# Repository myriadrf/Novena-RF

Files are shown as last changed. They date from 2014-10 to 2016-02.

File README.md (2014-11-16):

# Myriad-RF Module for the Novena Open Hardware Computing Plaform

This repository contains the design and manufacturing files for an RF module that adds 300MHz-3.8GHz broadband SDR transmit/receive capability to the [Novena Open Hardware Computing Platform](http://www.kosagi.com/w/index.php?title=Novena_Main_Page), along with RTL sources for interfacing implemented in the Novena FPGA.

## Contents

The directory structure for the hardware designs is as follows:

      /hardware/<version>/
          BOM/                   - bill of materials spreadsheet
          Gerbers/               - Gerber CAM files
          KiCAD/                 - KiCAD schematic and layout files
          Manufacturing/         - Additional manufacturing information
          PDF/                   - Schematic and layout PDFs
          Reports/               - DRC, ERC and drill reports

## Licensing

### Hardware design

The hardware design is licensed under a Creative Commons Attribution 3.0 Unported licence.

### FPGA design

The FPGA RTL is licensed under the Apache License, Version 2.0. However, please note that this does not extend to any files provided with the Xilinx design tools and see the relevant files for the associated terms and conditions.

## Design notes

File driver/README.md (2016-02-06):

# Myriad-RF Module SDR driver

This directory contains the complete SDR driver for the Myriad-RF Module.

## Contents

* fpga/ - FPGA project bridging LMS6002D to the EIM bus
* kernel/ - memory mapped access to sample/packet buffers
* host/ - host wrapper through a SoapySDR support module
* binary/ - pre-built FPGA image and kernel module

## Driver properties

### Configurable sample rates

* Max rate: 15.36 Msps
* Decimations: 1, 2, 4, 8, 16
* Interpolations: 1, 2, 4, 8, 16

### Selectable TX antenna switches

* "HB" - High band output (1500 - 3800 MHz)
* "BB" - Broadband output

The names for these switches can be used in the setAntenna() API call.

### Selectable RX antenna switches

* "LB" - Low band input (300 - 2200 MHz)
* "HB" - High band input (1500 - 3800MHz)
* "BB" - Broadband input

The names for these switches can be used in the setAntenna() API call.

### TX and RX Baseband filters

* 1.5 MHz to 28.0 MHz

### Adjustable transmit gain

* Overall: 0.0 to 56.0  dB
* "VGA1": -35.0 to -4.0 dB
* "VGA2": 0.0 to 25.0 dB

The names for these gain elements can be used in the setGain() API call.

### Adjustable receive gain

* Overall: 0.0  to 36.0  dB
* "VGA2": 0.0  to 30.0  dB
* "VGA1": 0.0  to 30.0  dB
* "LNA": 0.0  to 6.0  dB

The names for these gain elements can be used in the setGain() API call.

## Installing drivers

The following instructions allow one to build the driver for NovenaRF.
The instructions are intended for building locally on the device (for now).

### Dependencies

```
sudo apt-get install cmake g++ libusb-1.0-0-dev git
sudo apt-get remove libi2c-dev #fixes build issue
```

### Build the host driver

SoapySDR is a modular library and API for SDR devices.
First install the SoapySDR library:
https://github.com/pothosware/SoapySDR/wiki/BuildGuide

Then build and install the Novena RF support module:

```
git clone https://github.com/myriadrf/Novena-RF.git
cd Novena-RF/driver/host
mkdir build
cd build
cmake ../
make
sudo make install
sudo ldconfig
```

### Setup permissions and resources

There is a compiled FPGA image and kernel module in binary/
To install the files and to set the system permissions:

```
cd Novena-RF/driver/binary
sudo ./prepare_novena_rf.sh
```

Note: this script should be run after each reboot to set permissions and to load the module.

If, upon running the script, you get the error “could not insert module novena\_rf.ko: Invalid module format”, this means that the prebuilt `novena_rf.ko` doesn't match your kernel. Run `uname -a` to get the full version of your running kernel and `ls novena_rf.ko.*` to see if there's a matching version that you can copy over `novena_rf.ko`. If not, see the section below on building the kernel module.

## Hello Novena RF

Check that the installation detects NovenaRF support:

```
SoapySDRUtil --make="driver=novena"
```

## Platforms

### GNU Radio

Use the NovenaRF in GNU Radio through the gr-osmosdr API.
The user will have to install GNU Radio and SoapySDR first,
then install gr-osmosdr through the official project.
Make sure that soapy is one of the enabled components:

```
git clone git://git.osmocom.org/gr-osmosdr
cd gr-osmosdr/
```

## Pothos

Use the NovenaRF through Pothos SDR source and sink blocks
which support advanced timed streaming and burst controls.
Install SoapySDR first before following the build guide:
https://github.com/pothosware/pothos/wiki/BuildGuide

## osmo-trx

This is a branch of osmo-trx with novena support:
https://github.com/pothosware/osmo-trx/tree/novena\_support

## Advanced

### Build the FPGA image

Build the FPGA image with Xilinx ISE 14.\*.
The project is fpga/novena\_rf/novena\_rf.xise

### Build the kernel module

This is an out of tree kernel module and needs a full build of the kernel to compile against. Since a full kernel build can take a long time on the Novena, these instructions are for cross-compiling the kernel on another (more powerful) machine.

Download one of the available ARM toolchains:
http://boundarydevices.com/toolchains-i-mx6/. For example, the toolchain used below can be found [here](https://launchpad.net/linaro-toolchain-binaries/+milestone/2012.04).

Clone the linux kernel branch for Novena:

```
git clone https://github.com/xobs/novena-linux.git
cd novena-linux
```

You need to build a kernel that matches the one that you're running as closely as possible. Run `apt-cache show linux-image-novena | grep Version` to get the version number, which should look something like `3.19-novena-r39`. Then run `git tag | grep novena` to list the available tags and match the running version, hopefully exactly.

Instructions for building the kernel have been borrowed from this site:
http://boundarydevices.com/cross-compile-i-mx6-kernel-using-ltib-toolchain/

```
export PATH=/opt/toolchains/gcc-linaro-arm-linux-gnueabi-2012.04-20120426_linux/bin/:$PATH
export ARCH=arm
export CROSS_COMPILE=arm-linux-gnueabi-
make novena_defconfig
make -j5 zImage modules
```

Now build the kernel module from `Novena-RF/driver`:

```
cd kernel
make ARCH=arm KDIR=path/to/novena-linux
ls novena_rf.ko #output
```

## Licensing

The FPGA RTL, kernel source, and host wrapper are licensed under the Apache License, Version 2.0.
However, please note that this does not extend to any files provided with the Xilinx design tools and see the relevant files for the associated terms and conditions.

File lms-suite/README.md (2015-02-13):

# LMS Suite

Utilities for use with Myriad-RF hardware based upon FPRF transceivers from Lime Microsystems.

The utilities:

* can be used to calibrate the transceiver;
* allow configuration of the transceiver plus support devices such as clock generators;
* provide an FFT display.

Please note that the strategic solution is a single binary called *lms-suite*. However, at the time of writing this software only supports the Novena-RF module.

Owners of Reference Development Kit (Myriad-RF 1 + DE0-Nano interface/Zipper) and RASDR (Myriad-RF 1 + DigiRED) hardware should use the board-specific legacy software for the present time.

## Legacy

### ctr_6002dr2_myriad

This is for use with the original DE0-Nano interface board and is a Windows-only application.

### control_LMS6002

This is for use with the Zipper interface board (FMC and HSMC) and can be built for Windows or Linux.

### FFTviewer

This is for use with the DE0-Nano and RASDR DigiRED interfaces, and can be built for Windows or Linux.

Licence
-------

This software is published under the Apache License Version 2.0.

For further details please see the [COPYING](https://raw.github.com/myriadrf/myriadrf-utils/master/COPYING) file.

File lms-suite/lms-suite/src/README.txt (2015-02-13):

Lime microsystems suite (2014-11-11)

1. What is it?
--------------
This software bundle is designed for configuring LMS6002 transceiver boards.
Currently supported boards: EVB6, DigiGreen, DigiRed, Zipper.
This software can run on Windows and Linux operating systems.

2. Compiling
------------
Project can be compiled on Windows or Linux operating system using CodeBlocksIDE
or using Make files on Linux. This project uses wxWidgets-3.0, fftw3 libraries. 
On Linux system additional libusb-1.0 library is required. wxWidgets must be 
compiled with openGL support.

Libraries can be downloaded from the following links:
	http://www.wxwidgets.org
	http://www.fftw.org

To build software using CodeBlocks IDE, open the project lms-suite.cbp. Adjust
project compiler and linker search paths according to your system configuration.
Select "Release" target and build it. The built software executable will be 
placed in lms-suite/bin directory.

On Linux operating system, to build software using Make files, open command line
and navigate to project directory. Execute 'make release' command and wait for 
the compilation process to complete. The built software executable will be 
placed in lms-suite/bin directory.

For additional information how to compile this software read compilation_guide
documents

3. Additional notes
-------------------
When running this software on Linux, it should be executed with admin privileges,
or the USB device permissions has to be changed to allow non admin users to use it.

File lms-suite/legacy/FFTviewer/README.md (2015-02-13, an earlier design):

# FFT viewer and ctr_6002dr2 software

1. Archive directory structure:
	./src/GUI - directory with source code for FFT viewer
	./src/Logic - directory with source code for ctr_6002dr2
	./src/wxsmith - FFT viewer gui defintions for CodeBlocks WxSmith plugin
	./src/Logic/dependencies - additional libraries needed to compile ctr_6002dr2 and FFT viewer
	./bin - Windows binaries
	
2. Description
	This software is designed to control LMS6002 chip and Myriad RF board.
	The FFT viewer collects I,Q channel data samples and performs FFT calculations,
	then displays results in graphs.
	
	This software can be compiled and executed on Windows and Linux operating systems.
	On Windows operating systems FFT viewer uses Cypress USB library to communicate
	with devices, on Linux operating system it is replaced by LibUSB library.
	
3. Compiling
	This archive contains project file for CodeBlocks IDE and which is compiled 
	by using GCC compiler, it has build targets	configured for Windows and Linux
	versions. Open project and select build target ReleaseWin32 or ReleaseLinux 
	depending on your operating system.	For windows version you need to change
	compiler, linker and resource compiler search paths to wxWidgets library directory.
	These settings can be found in project properties->Build targets, select GUIReleaseWIN32
	and open Build options. In search directories tab add needed directories.
	
	On Windows this software requires to be linked with:
	fftw3f, pthreads, libCyAPI_fx3_GCC.a, wxWidgets libraries

	On Linux this software requires to be linked with:
	libusb-1.0, fftw3f, pthreads, wxWidgets
	
4. Additional info
	On linux this software requires admin rights, otherwise it will be unable 
	to use USB device, also connected chips are discovered only at launch of
	this software.

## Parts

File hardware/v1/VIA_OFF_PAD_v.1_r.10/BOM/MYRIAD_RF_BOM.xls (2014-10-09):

Value | QTY | Designator | Package | Description | Manufacturer Part Number | Manufacturer | Vendor | Vendor Part Number | Assemble
0.5pF | 2 | C33 C120 | C_SM0402 | CAP; CER; 0.5PF; 50V; NPO; 0402; | CC0402CRNPO9BNR50 | Yageo | Digi-Key | 311-1001-2-ND
1.0pF | 3 | C21 C34 C72 | C_SM0402 | CAPACITOR; NP0; 0402; 1PF; | GJM1555C1H1R0BB01D | MURATA | Farnell | 1889196
1.2pF | 3 | C36 C44 C49 | C_SM0402 | CAP; CER; 1.2PF; 100V; NP0; 0402; | CBR04C129B1GAC | KEMET | Digi-Key | 399-8598-1-ND
1.8pF | 3 | C91 C92 C93 | C_SM0402 | CAP; CER; 1.8PF; 100V; NP0; 0402; | CBR04C189B1GAC | KEMET | Digi-Key | 399-8596-1-ND
3.9pF | 2 | C94 C95 | C_SM0402 | CAP; CER; 3.9PF; 100V; NP0; 0402; | CBR04C399B1GAC | KEMET | Digi-Key | 399-8588-1-ND
8.2pF | 2 | C31 C68 | C_SM0402 | CAPACITOR; NP0; 0402; 50V; 8.2PF; | C0402C829C5GACTU | KEMET | Farnell | 1865418
10pF | 1 | C221 | C_SM0402 | CAPACITOR CERAMIC 10PF 50V; C0G; 1%; 0402 | MC0402N100F500CT | MULTICOMP | Farnell | 1709776
33pF | 13 | C53 C55 C73 C78 C105 C106 C109..C115 | C_SM0402 | CAPACITOR; 0402; NP0; 16V; 33PF; | MCCA000902 | MULTICOMP | Farnell | 1856052
100pF | 13 | C26 C27 C51 C54 C56 C57 C59 C60 C61 C63 C69 C77 C101 | C_SM0402 | CAPACITOR; 0402; 100PF; 50V; | GRM1555C1H101JD01D | MURATA | Farnell | 8819572
150pF | 2 | C15 C18 | C_SM0402 | MLCC; 0402; NP0; 50V; 150PF; | MCCA000122 | MULTICOMP | Farnell | 1758976
470pF | 2 | C13 C16 | C_SM0402 | MLCC; 0402; X7R; 50V; 470PF; | MCCA000132 | MULTICOMP | Farnell | 1758987
1nF | 1 | C29 | C_SM0402 | CAP; CER; 1000PF; 50V; X7R; 0402; | CC0402KRX7R9BB102 | Yageo | Digi-Key | 311-1036-1-ND
10nF | 4 | C14 C17 C25 C136 | C_SM0402 | CAPACITOR; 0402; 10NF; 16V; | CC0402KRX7R7BB103 | YAGEO (PHYCOMP) | Farnell | 3019275
100nF | 26 | C3 C4 C7..C12 C19 C28 C30 C32 C35 C74..C76 C82 C84 C85 C90 C216..C220 C224 | C_SM0402 | CAPACITOR; 0402; 100NF; 10V; X5R; | C0402C104K8PACTU | KEMET | Farnell | 1288282
1uF | 5 | C1 C2 C5 C6 C20 | C_SM0402 | MLCC; 0402; X5R; 10V; 1UF; | MCCA000506 | MULTICOMP | Farnell | 1759381
1uF | 6 | C22 C23 C81 C88 C122 C144 | C_SM0603 | CAPACITOR; 0603; 1UF; 10V; X5R; 10%; | CC0603KRX5R6BB105 | YAGEO (PHYCOMP) | Farnell | 9402080
2.2uF | 2 | C24 C117 | C_SM0603 | CAPACITOR; 0603; X5R; 10V; 2.2UF; | GRM188R61A225KE34D | MURATA | Farnell | 1828799
10uF | 3 | C52 C222 C223 | C_S0603 | CAPACITOR; 10UF; 10V; X5R; 0603; | LMK107BJ106MALTD | TAIYO YUDEN | Farnell | 2113070RL
LD1117DT33 | 1 | DA1 | DPAK2 | LD1117DT33 - V REG LDO +3.3V; SMD; 1117; DPAK-3 | LD1117DT33 | STMICROELECTRONICS | Farnell | 1087169
LMS6002DR2 | 1 | DA3 | DQFN-120 | LMS6002 Tranceiver; DQFN-120; | LMS6002DFN | Lime Microsystems | Digi-Key | 1434-1000-1-ND
PE42440 | 1 | DA5 | QFN-16 | IC RF SWITCH; SP4T; 50 OHM; 16QFN; | PE42440 | Peregrine Semiconductor | Digi-Key | 1046-1038-1-ND
PE42422 | 1 | DA6 | QFN12 | IC; RF SWITCH; SPDT; 50 OHM; 12QFN; | PE42422MLAA-Z | Peregrine Semiconductor | Digi-Key | 1046-1062-1-ND
LP2985IM5-1.8 | 2 | DA2 DA7 | SOT23-5 | LP2985IM5-1.8/NOPB - IC; REG; LDO; 1.8V; 150MA; SOT23 | LP2985IM5-1.8/NOPB | NATIONAL SEMICONDUCTOR | Farnell | 1564761RL
CDCV304PW | 1 | DA4 | TSSOP-8 | CDCV304PWR - IC; CLOCK BUFFER; | CDCV304PWR | TEXAS INSTRUMENTS | Farnell | 1703244
Shield | 1 | EK1 | EK | EMI Gaskets & Earth Pads 204 Frame & Case | BMIS-204-F; BMIS-204-C; | Laird Technologies | Mouser | 739-BMIS-204-F; 739-BMIS-204-C;
4.7nH | 4 | L17 L22 L34 L35 | L_SM0402 | Inductor; 4.7 nH; 0402; 5%; | 0402HP-4N7X_LU | Coilcraft | Coilcraft | 0402HP-4N7X_LU
5.6nH | 3 | L27 L28 L29 | L_SM0402 | Inductor; 5.6 nH; 0402; 5%; | 0402HP-5N6XJLU | Coilcraft | Coilcraft | 0402HP-5N6XJLU
12nH | 3 | L32 L36 L37 | L_SM0402 | Inductor; 12 nH; 0402; 5%; | 0402HP-12NX_LU | Coilcraft | Coilcraft | 0402HP-12NX_LU
12nH | 2 | L38 L40 | L_SM0402 | Inductor; 12 nH; 0402; 5%; | 0402HP-12NX_LU | Coilcraft | Coilcraft | 0402HP-12NX_LU | NOFIT
15nH | 1 | L26 | L_SM0402 | Inductor; 15 nH; 0402; 5%; | 0402HP-15NX_LU | Coilcraft | Coilcraft | 0402HP-15NX_LU
22nH | 1 | L42 | L_SM0402 | Inductor; 22 nH; 0402; 5%; | 0402HP-22NX_LU | Coilcraft | Coilcraft | 0402HP-22NX_LU
36nH | 4 | L11 L12 L13 L33 | L_SM0402 | Inductor; 36 nH; 0402; 5%; | 0402CS-36NX_LU | Coilcraft | Coilcraft | 0402CS-36NX_LU
LED | 1 | LD1 | LD0603 | OSRAM - LGQ971 - LED; SMD; GREEN; | LGQ971 | OSRAM | Farnell | 1226372RL
0 | 14 | R4 R5 R12 R18 R23 R24 R25 R26 R27 R28 R29 R42 R139 R164 | R_SM0402 | RESISTOR; 0402; 0R; REEL 10000; | RC0402JR-070RL | YAGEO (PHYCOMP) | Farnell | 1117280
0 | 4 | R44 R46 R49 R153 | R_SM0402 | RESISTOR; 0402; 0R; REEL 10000; | RC0402JR-070RL | YAGEO (PHYCOMP) | Farnell | 1117280 | NOFIT
0 | 2 | R1 R82 | R_SM0805 | RESISTOR; RC11; 0805; 0R; | RC0805JR-070RL | YAGEO (PHYCOMP) | Farnell | 9233750
22 | 7 | R16 R17 R38 R39 R45 R47 R48 | R_array | RESISTOR ARRAY; ARV341; 0804; 22R; | YC124-JR-0722RL | YAGEO (PHYCOMP) | Farnell | 9235264
22 | 2 | R74 R75 | R_SM0402 | RESISTOR; 0402; 22R; 1%; REEL 10000; | RC0402FR-0722RL | YAGEO (PHYCOMP) | Farnell | 1117301
47 | 5 | R130 R131 R132 R133 R134 | R_SM0402 | RESISTOR; 0402; 47R; 1%; REEL 10000; | RC0402FR-0747RL | YAGEO (PHYCOMP) | Farnell | 1117311
49.9 | 1 | R69 | R_SM0402 | RESISTOR; 0402; 1%; 49R9; | MC 0.0625W 0402 1% 49R9 | MULTICOMP | Farnell | 1802906RL
51 | 4 | R59 R60 R63 R64 | R_SM0402 | RESISTOR; 0402; 0.063W; 1%; 51R; | RC0402FR-0751RL | YAGEO (PHYCOMP) | Farnell | 1458803RL
390 | 1 | R35 | R_SM0402 | RESISTOR; RC32H; 0402; 390R; | RC0402FR-07390RL | YAGEO (PHYCOMP) | Farnell | 9239189
470 | 1 | R43 | R_SM0402 | RESISTOR; RC32H; 0402; 470R; | RC0402FR-07470RL | YAGEO (PHYCOMP) | Farnell | 9239197
820 | 2 | R31 R33 | R_SM0402 | RESISTOR; 0402; 1%; 820R; | MC 0.0625W 0402 1% 820R | MULTICOMP | Farnell | 1358040RL
1K2 | 2 | R30 R32 | R_SM0402 | RESISTOR; 0402; 1%; 1K2; | MC 0.0625W 0402 1% 1K2 | MULTICOMP | Farnell | 1358045
6K8 | 1 | R36 | R_SM0402 | RESISTOR; 0402; 1%; 6K8; | MC 0.0625W 0402 1% 6K8 | MULTICOMP | Farnell | 1358064
10K | 7 | R83 R84 R85 R94 R95 R96 R98 | R_SM0402 | RESISTOR; THICK FILM; 10KOHM; 62.5mW; 1%; | RC0402FR-1310KL | YAGEO | Farnell | 1799235
12K | 1 | R34 | R_SM0402 | RESISTOR; 0402; 1%; 12K; | MC 0.0625W 0402 1% 12K | MULTICOMP | Farnell | 1358071RL
1M | 3 | R2 R3 R50 | R_SM0402 | RESISTOR; THICK FILM; 1MOHM; 62.5mW; 1%; | RC0402FR-071ML | YAGEO | Farnell | 2127667
100MHz/600/0.2A | 16 | R6 R7 R8 R9 R10 R11 R13 R14 R15 R19 R20 R21 R22 R37 R40 R87 | R_SM0402 | FERRITE BEAD; 600R; 0.25A; 0402; | 7427927161 | WURTH ELEKTRONIK | Farnell | 1961693
100MHz/60/1A | 3 | R41 R211 R215 | R_SM0805 | FERRITE BEAD; 0805; 60 OHM; | MMZ2012Y600B | TDK | Farnell | 1669733
POT | 1 | RT1 | RT_SMD | 43WR10KLFTR | TT Electronics/BI | Digi-Key | 987-1030-2-ND
TC1-1-13MA+ | 1 | T1 | TC1-1-13MA+ | RF Transformer; 4.5 - 3000 MHz; RF Power 0.25 Watt; Ratio 1:1; 50 Ohm; | TC1-1-13MA+ | Mini-Circuits | Municom | TC1-1-13MA+
TC4-25X+ | 1 | T2 | TC1-1-13MA+ | RF Transformer; 500 - 2500 MHz; RF Power 0.25 Watt; Ratio 1:4; 50 Ohm; | TC4-25X+ | Mini-Circuits | Municom | TC4-25X+
FX10A-80P8 | 1 | X3 | FX10A-80P8 | CONN HEADER; 80POS; W/O; POST; SMD; | FX10B-80P/8-SV1(71) | Hirose Electric | Digi-Key | H11228-ND
5-146285-2 | 1 | X2 | pinhead2 | BOARD-BOARD CONNECTOR HEADER; 2WAY; 1ROW; | 5-146285-2 | TE CONNECTIVITY / AMP | Farnell | 1341684
CONN_6 | 1 | X9 | pinhead6 | Headers & Wire Housings 06; MODII; HDR SRST; B/A; W/HD; | 104345-4 | TE Connectivity | TTI | 104345-4
U.FL | 2 | X6 X7 | U.FL | CONN; UMC; RCPT; STR; 50 OHM; SMD; | 734120110 | Molex Inc | Digi-Key | WM5587CT-ND
5-104348-3 | 2 | X4 X5 | VR_pinhead5 | .100 inch AMPMODU Headers; RIGHT ANGLE; 5WAY; | 5-104348-3 | TE Connectivity | TTI | 5-104348-3
RTX5032A_30.72MHZ | 1 | XO2 | SMD_RTX5032A | RTX5032A; 30.720 MHz; | 509464 | Rakon | Rakon | 509464 | NOFIT
RACON_TXCO_NF | 1 | XO1 | SMD_TXCO | 30.72 MHz; TCVCXO; for Femtocells; | E5280LF | Rakon | Rakon | E5280LF

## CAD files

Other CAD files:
lms-suite/legacy/ctr_6002dr2_myriad/src/frMain.obj
lms-suite/legacy/ctr_6002dr2_myriad/src/frBoard2.obj
lms-suite/legacy/ctr_6002dr2_myriad/src/About.obj
lms-suite/legacy/ctr_6002dr2_myriad/src/dgRFIFParam.obj
lms-suite/legacy/ctr_6002dr2_myriad/src/frRxVGA2.obj
lms-suite/legacy/ctr_6002dr2_myriad/src/clUARFCN.obj
lms-suite/legacy/ctr_6002dr2_myriad/src/dgRefClk.obj
lms-suite/legacy/ctr_6002dr2_myriad/src/frTxPLL.obj
lms-suite/legacy/ctr_6002dr2_myriad/src/common.obj
lms-suite/legacy/ctr_6002dr2_myriad/src/frRxFe.obj
lms-suite/legacy/ctr_6002dr2_myriad/src/frCustomer.obj
lms-suite/legacy/ctr_6002dr2_myriad/src/frFreqVsCap.obj
lms-suite/legacy/ctr_6002dr2_myriad/src/frBoard.obj
lms-suite/legacy/ctr_6002dr2_myriad/src/frTxLpf.obj
lms-suite/legacy/ctr_6002dr2_myriad/src/register_map.obj
lms-suite/legacy/ctr_6002dr2_myriad/src/dlgVcoCapLog.obj
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

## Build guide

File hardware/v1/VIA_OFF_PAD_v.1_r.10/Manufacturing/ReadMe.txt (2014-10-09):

Board Description
-----------------

board designation           : MYRIAD RF / Novena 
board version		    : version 1, revision 10	
board type                  : Lead Free
board size                  : 48.0 mm x 44.00 mm (plus mounting via edge 6.00 mm x 6.00 mm)
board thickness             : 1.6 mm +/- 10 %
board material              : IT-180A
number of layers            : 6

Top layer copper foil thickness: 17.5 um
Dielectric thickness between Top layer and 2nd layer: 173 um (6.8 mils)
Dielectric between Top layer and 2nd layer relative permittivity (Er): 4.2

minimum finished hole size  :  200 um
minimum spacing             :  100 um
minimum track width         :  100 um

drill diameters             : finished hole

plating finish (both sides) : immersion gold
                              0.05-0.10 um of gold over
                              2.50-5.00 um of nickel

Important Notes
---------------

DRCs must be run on Gerber files before building boards.

All through hole vias may be plated shut.

Solder mask : black TAIYO, both sides, halogen free.

Silkscreen : white epoxy ink, halogen free, both sides.

Electrical test : 100 % netlist.

Boards are to be individually bagged.

Design software used:  KiCad

Controlled Impedance
--------------------

  * 50 Ohm coated single ended microstrip (Top layer) track width 310 um

Board Stackup
----------------

1. Solder Paste Front		: MYRIAD_RF-F_Paste.gtp
2. Silk Screen Front		: MYRIAD_RF-F_SilkS.gto
3. SolderMask Front		: MYRIAD_RF-F_Mask.gts

4. Front Layer			: MYRIAD_RF-Front.gtl
5. Inner GND Layer		: MYRIAD_RF-Inner_GND.gbr																	
6. Inner Analog Signal Layer	: MYRIAD_RF-Inner_Analog_Signal.gbr
7. Inner Power Layer		: MYRIAD_RF-Inner_Power.gbr
8. Inner Digital Signal Layer	: MYRIAD_RF-Inner_Digital_Signal.gbr
9. Back Layer			: MYRIAD_RF-Back.gbl

10. SolderMask Back		: MYRIAD_RF-B_Mask.gbs
11. Silk Screen Back		: MYRIAD_RF-B_SilkS.gbo
12. Solder Paste Back      	: MYRIAD_RF-B_Paste.gbp

--------------------------------------------------
13. PCB edges           	: MYRIAD_RF-Edge_Cuts.gbr
14. Drawings			: MYRIAD_RF-Dwgs_User.gbr

15. Drill map            	: MYRIAD_RF-drl_map.pho
16. NC Drill file	 	: MYRIAD_RF.drl

Reports folder
--------------
                  
MYRIAD_RF_erc.txt
MYRIAD_RF.net.txt
MYRIAD_RF_drc.txt
MYRIAD_RF-drl.rpt.txt
MYRIAD_RF_all_models.txt

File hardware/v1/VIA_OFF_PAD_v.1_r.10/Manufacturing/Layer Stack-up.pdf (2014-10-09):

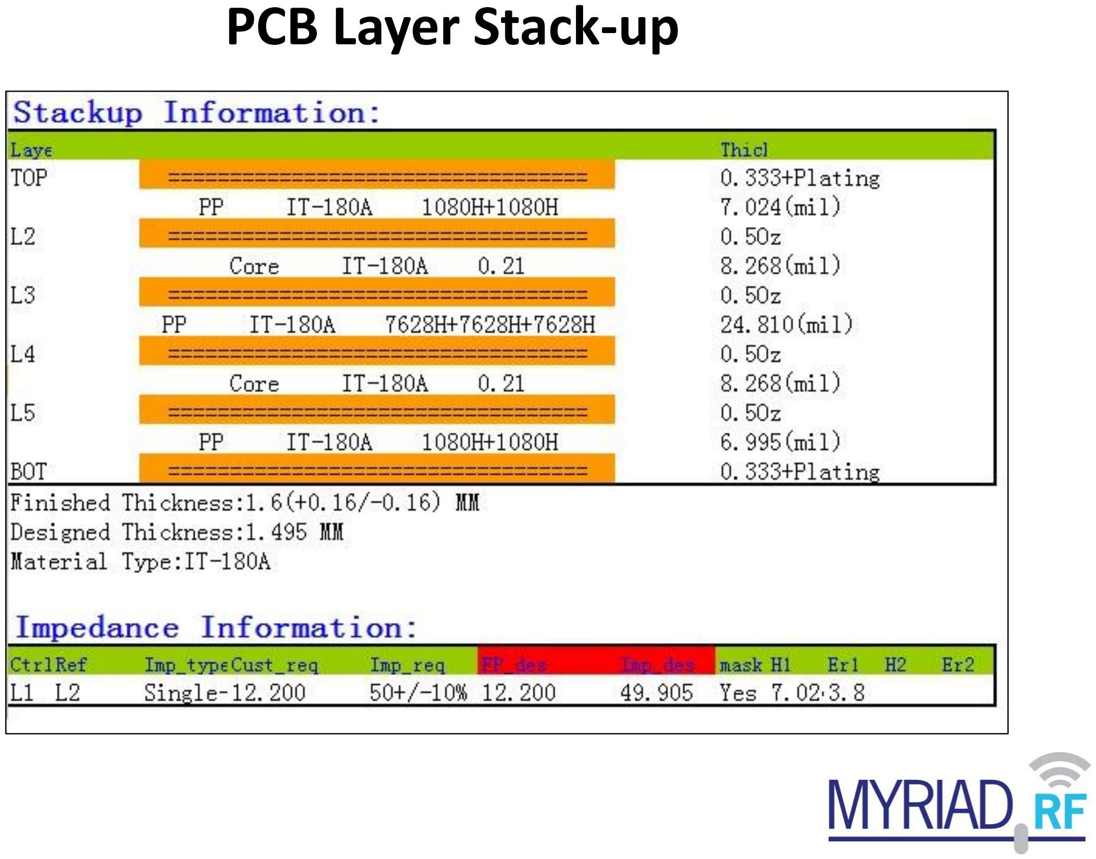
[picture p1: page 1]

PCB Layer Stack-up

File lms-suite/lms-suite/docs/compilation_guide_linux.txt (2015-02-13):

This is a compilation guide for LMS Suite on Linux operating system.

1. Requirements
    To compile LMS Suite software the following libraries are required to be
    installed on your system: wxWidgets, usb-1.0 and fftw3 libraries. Also CMake
	system is required to generate makefiles

2. Installing required libraries

    If you don't already have these libararies please install them with
    the following command:
        sudo apt-get install libwxgtk3.0-dev libfftw3-dev libusb-1.0

    If libwxgtk3.0-dev library is not available from your package repositories,
    it is advised to download wxWidgets library directly from 
    https://www.wxwidgets.org/downloads/. Extract the wxWidgets source code archive.
    Open command line interface(terminal) and change working directory into
    wxWidgets source code folder.
        e.g. cd /home/user/Downloads/wxWidgets-3.0
    Then execute the following commands:
        ./configure
        make  #this command can take quite a while depending on your system power
        sudo make install
    After these commands wxWidgets will be installed on your system.
	
	Install CMake system with the following command:
		sudo apt-get install cmake

3. Compiling LMS Suite
    Open command line(terminal).
    Change working directory to lms-suite source folder.
        e.g cd /home/user/Downloads/lms-suite/src
    Execute the following command:
        mkdir build && cd build && cmake .. && cmake --build .		
		
    Wait for the compilation process to complete
    The compiled application executable will be placed inside build folder

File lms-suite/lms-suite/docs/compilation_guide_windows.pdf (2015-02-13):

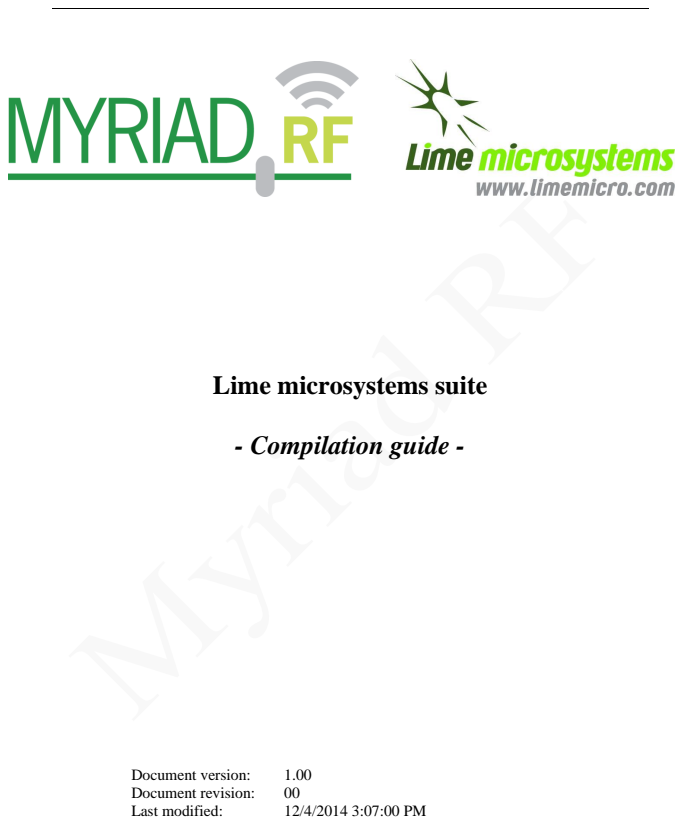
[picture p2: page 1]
- Compilation guide -; Document version:; Document revision:; Last modified:

Lime microsystems suite

# Contents

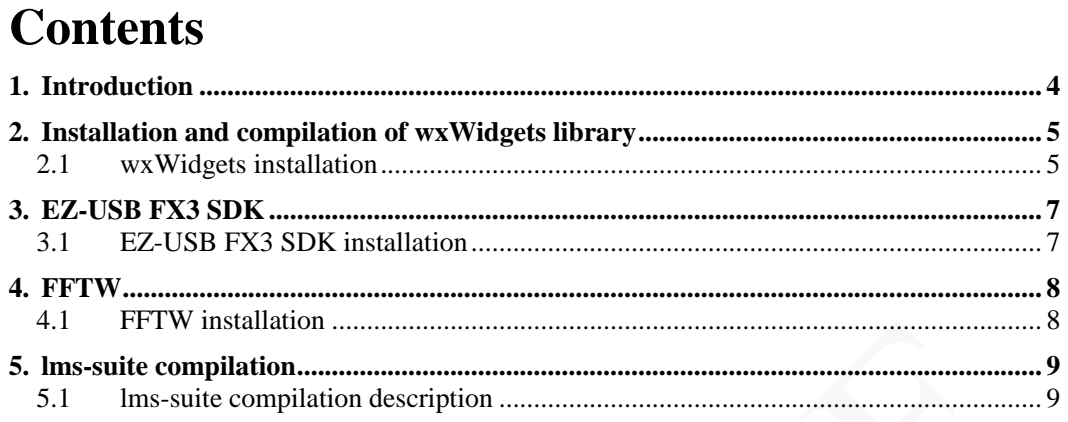
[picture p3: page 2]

# Revision History

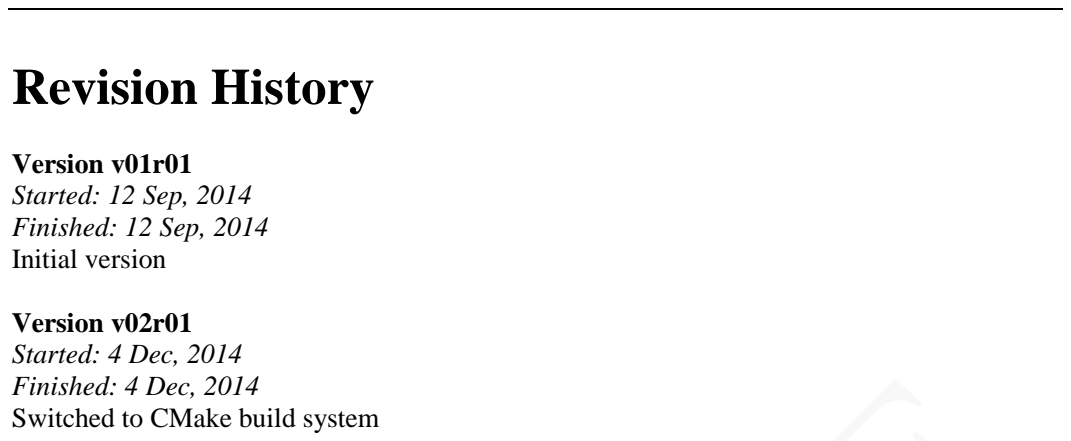
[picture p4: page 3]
Version v01r01 Started: 12 Sep, 2014 Finished: 12 Sep, 2014 Initial version

Version v02r01
Started: 4 Dec, 2014
Finished: 4 Dec, 2014
Switched to CMake build system

1

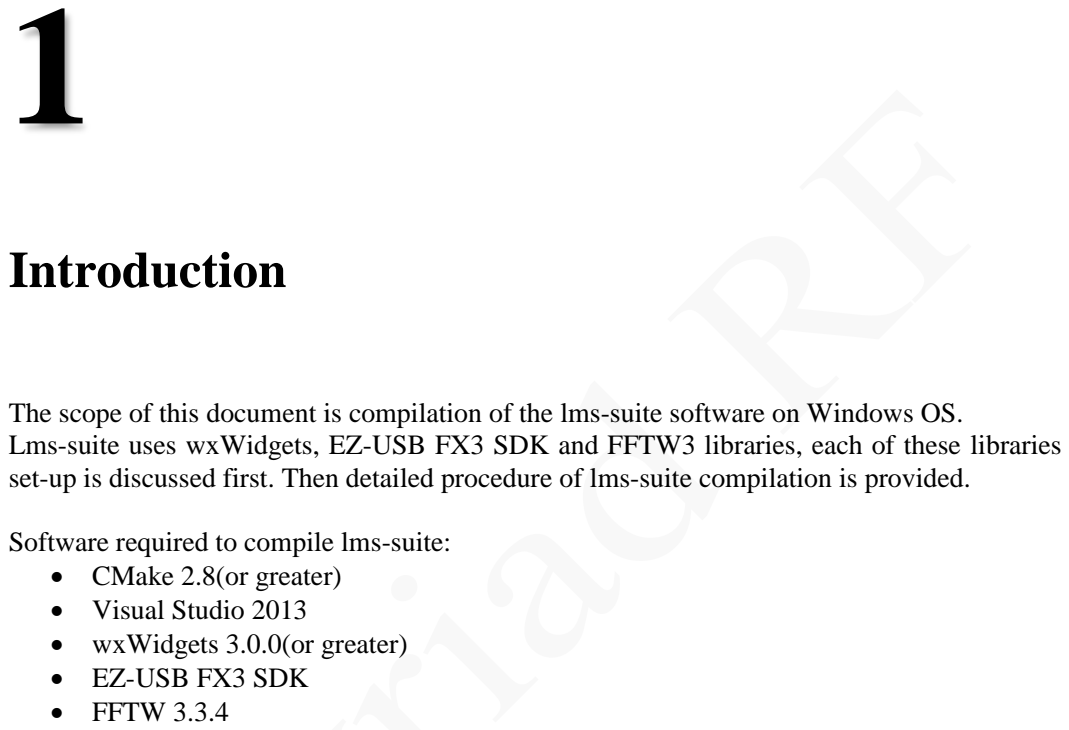
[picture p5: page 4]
Introduction

The scope of this document is compilation of the lms-suite software on Windows OS.
Lms-suite uses wxWidgets, EZ-USB FX3 SDK and FFTW3 libraries, each of these libraries
set-up is discussed first. Then detailed procedure of lms-suite compilation is provided.

Software required to compile lms-suite:
• CMake 2.8(or greater)
• Visual Studio 2013
• wxWidgets 3.0.0(or greater)
• EZ-USB FX3 SDK
• FFTW 3.3.4

2

# Installation and compilation of wxWidgets library

Installation and compilation of wxWidgets library is covered in this chapter.

## 2.1 wxWidgets installation

Step by step instruction how to install, prepare and compile wxWidgets library is provided bellow:

1. Download wxWidgets source code or Installer from http://wxwidgets.org/downloads/
2. Install or extract wxWidgets 3.0.2 source code to the c:\wxWidgets-3.0.2\
3. Open C:\wxWidgets-3.0.2\build\msw\wx_vc12.sln Visual Studio 2013 solution
4. Select Release build as shown in Figure 1.

Figure 1 Selecting build target
5. Compile wxWidgets library by clicking PROJECT->BUILD SOLUTION as show in Figure 2

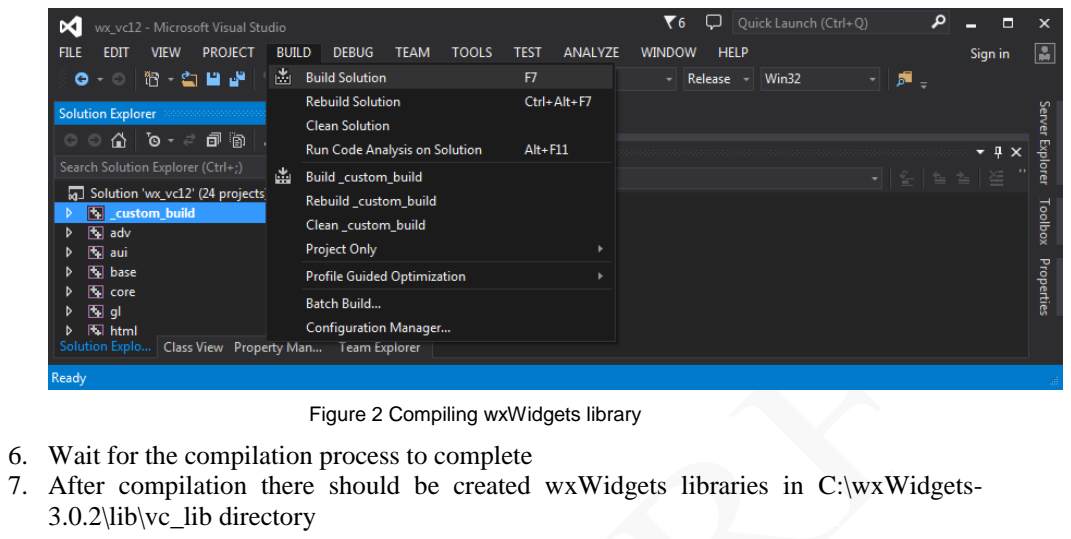
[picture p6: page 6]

Figure 2 Compiling wxWidgets library

6. Wait for the compilation process to complete
7. After compilation there should be created wxWidgets libraries in C:\wxWidgets-
3.0.2\lib\vc_lib directory

3

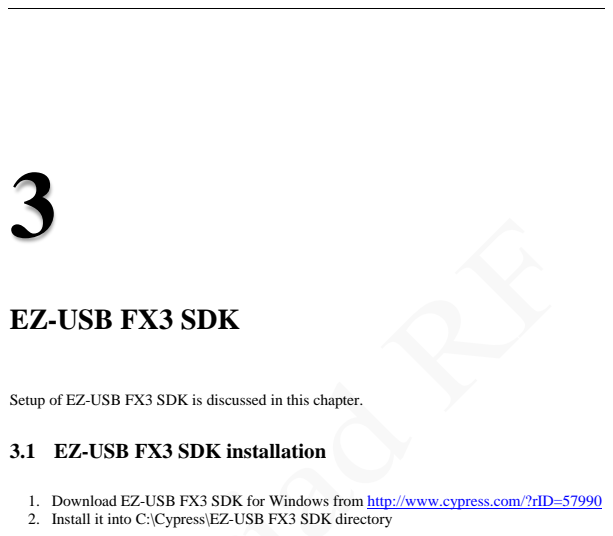
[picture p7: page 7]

EZ-USB FX3 SDK

Setup of EZ-USB FX3 SDK is discussed in this chapter.

3.1 EZ-USB FX3 SDK installation

1. Download EZ-USB FX3 SDK for Windows from http://www.cypress.com/?rID=57990
2. Install it into C:\Cypress\EZ-USB FX3 SDK directory

4

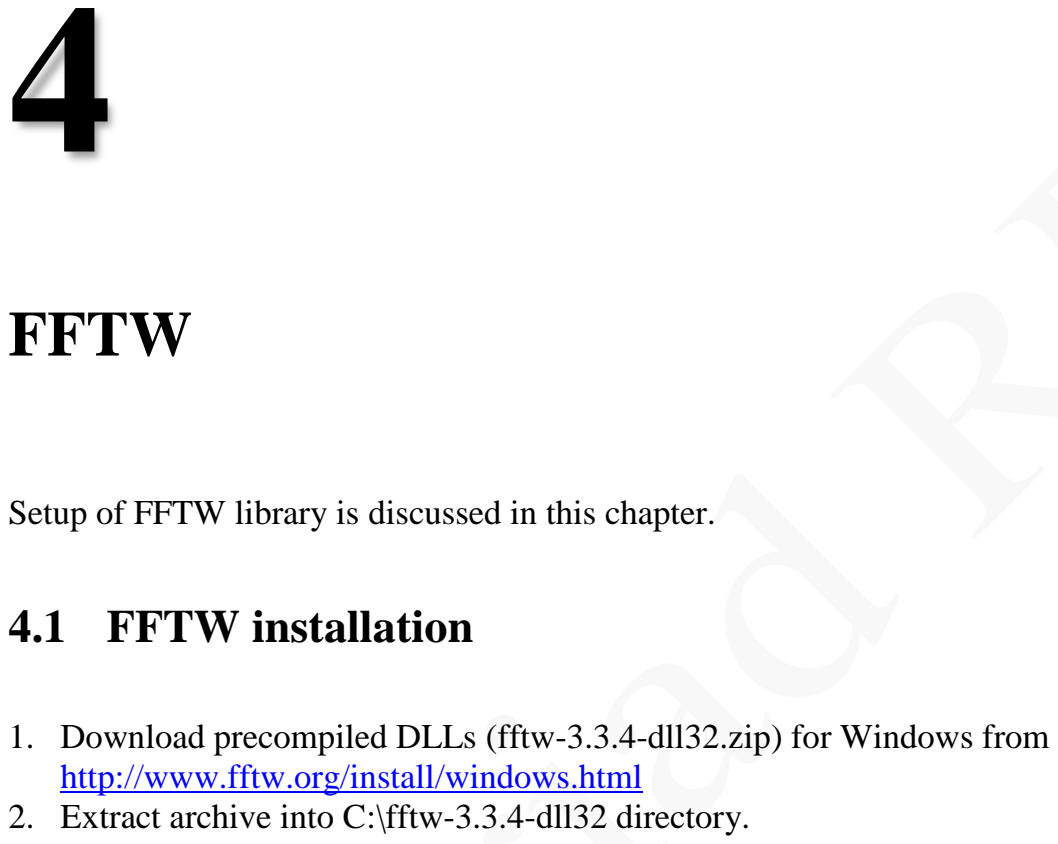
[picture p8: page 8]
FFTW; 4.1 FFTW installation

Setup of FFTW library is discussed in this chapter.

1. Download precompiled DLLs (fftw-3.3.4-dll32.zip) for Windows from
http://www.fftw.org/install/windows.html
2. Extract archive into C:\fftw-3.3.4-dll32 directory.

5

# lms-suite compilation

Compilation instructions of lms-suite software is discussed in this chapter.

## 5.1 lms-suite compilation description

Lms-suite uses CMake system to setup build projects for your environment. First you need to install CMake system, you can download it from http://www.cmake.org/download/. To configure lms-suite project CMake-gui will be used in the instructions.

1. Place lms-suite folder into C:\lms-suite directory
2. Run cmake-gui
3. Browse source to where lms-suite source code is located. (e.g. C:/lms-suite/lms-suite/src)
4. Browse Build to where you want to place created binaries (e.g. C:/lms-suite/lms-suite/build)
5. Click Congifure button
6. In popup menu select Use default native compilers as shown in Figure 3

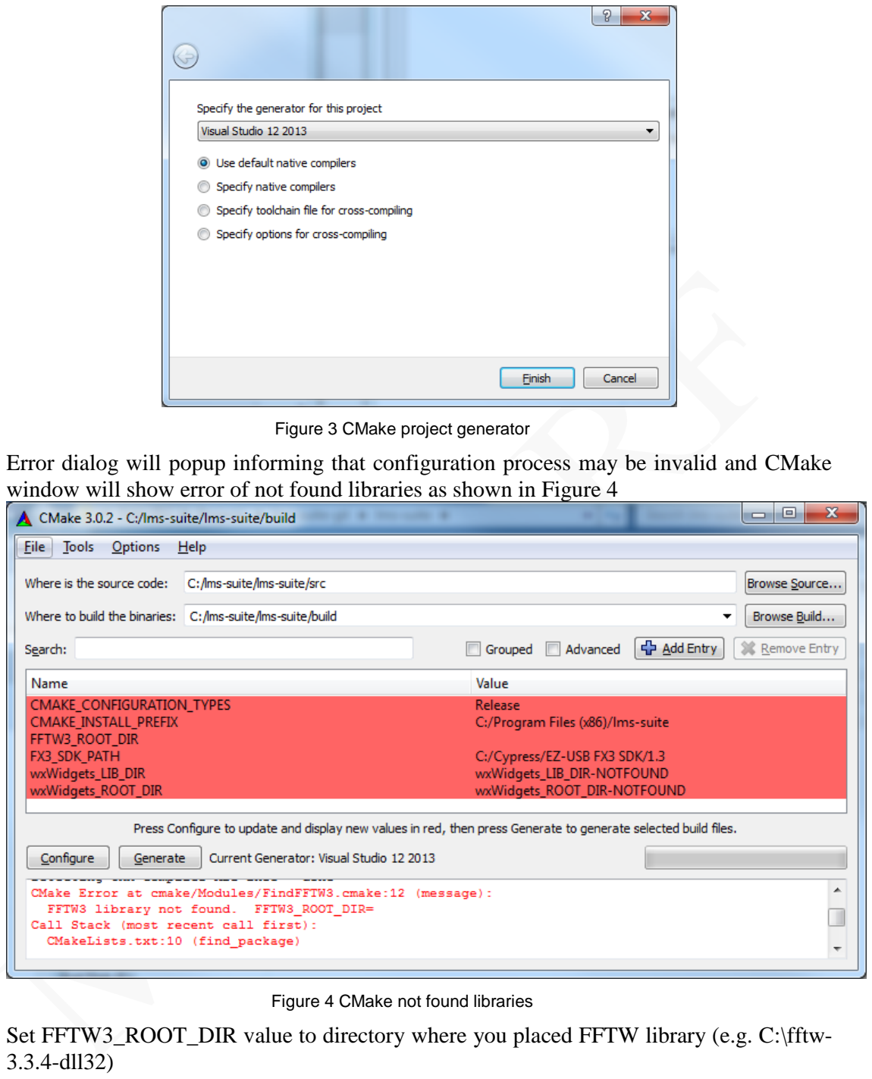
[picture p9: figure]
Figure 3 CMake project generator; Figure 4 CMake not found libraries; 3.3.4-dll32)

7. Error dialog will popup informing that configuration process may be invalid and CMake window will show error of not found libraries as shown in Figure 4
8. Set FFTW3_ROOT_DIR value to directory where you placed FFTW library (e.g. C:\fftw-
9. Set wxWidgets_ROOT_DIR value to directory where you placed wxWidgets library (e.g C:\wxWidgets-3.0.2)
10. Click Configure
11. Click Generate, this will create Visual Studio project inside your selected build directory
12. Open created project C:\lms-suite\lms-suite\build\lms-suite.sln
13. In Visual Studio menu select BUILD->Build Solution
14. Wait for compilation process to complete
15. Compiled binaries will be places inside build directory in Release folder
16. Execute lms-suite.exe, lms-suite needs to have libfftw3f-3.dll file in the same directory

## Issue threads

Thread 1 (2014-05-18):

adding mounting holes to pcb

mogorman, 2014-05-18:
The novena has 3 screw holes near the high-speed header.  Would it be possible to add any of them to this daughter board for more secure long term mounting.

Closed 2015-02-11.

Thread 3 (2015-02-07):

fpga - stream to/from BRAM blocks

guruofquality, 2015-02-07:
For interfacing between EIM with the framer/deframer.

guruofquality, 2015-02-08:
https://github.com/myriadrf/Novena-RF/blob/master/driver/fpga/dma_mm2s.vhdl
https://github.com/myriadrf/Novena-RF/blob/master/driver/fpga/dma_s2mm.vhdl

Closed 2015-02-08.

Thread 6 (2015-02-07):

fpga - registers for config/readback/settings

guruofquality, 2015-02-07:
* setting time
* getting time
* configuring addresses for BRAM to/from fifo
* lime resets/enables

guruofquality, 2015-02-08:
https://github.com/myriadrf/Novena-RF/blob/master/driver/fpga/novena_rf.vhdl#L211

Closed 2015-02-08.

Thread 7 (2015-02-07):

kernel - mapping for "DMA" space

guruofquality, 2015-02-07:
* need an mmap for the memory space used to read/write stream data

guruofquality, 2015-02-08:
https://github.com/myriadrf/Novena-RF/blob/master/driver/kernel/novena_rf_fops.c

Closed 2015-02-08.

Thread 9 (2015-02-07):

need IRQ between FPGA and host

guruofquality, 2015-02-07:
We need to be able to sleep with a timeout for read/writeStream when the stream is not ready.  We can select()/poll() on a userspace GPIO from sysfs. Just need to figure out a possible GPIO candidate between the FPGA and the arm. Suggestions appreciated.

guruofquality, 2015-02-12:
* Is there an available GPIO that we arent using (check schematic)?
* Is it possible to use EIM_WAIT as an irq (probably hard to do, needs kernel support)?
* Or re-purposing one of the 4 cpu_spi GPIOs, as all LMS GPIOs, antenna switches, and enables can eventually be driven from the register interface. And sen is already controlled through the sysfs GPIO anyway.

guruofquality, 2015-02-16:
* used ECSPI3_RDY https://github.com/myriadrf/Novena-RF/commit/620d0c852232656ad54bfa7c1c0d26e68c98c9af

Closed 2015-02-16.

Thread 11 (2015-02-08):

fpga - automatic switching for LMS IOs based on RX/TX state

guruofquality, 2015-02-08:
```VHDL
        --lms control signals
        lms_rxen : out std_logic;
        lms_txen : out std_logic;
        lms_lmsrst : out std_logic;
        mrf_gpio0 : out std_logic;
        mrf_gpio1 : out std_logic;
        mrf_gpio2 : out std_logic;
````

I dont know what the last three gpios are for, perhaps antenna switches. Currently, these IOs are controlled by a SPI-based state machine controlled by the ARM. It may be desirable to control these based on the ADC/DAC active signals coming from the framer/deframer; for the purposes of automatic antenna switching (if that is indeed their use case).

rvadoklis, 2015-02-09:
The RF switches on the RF board (MyraidRF board) are controlled via the GPIO 0-2 logic signals, provided by the FPGA module. This enables the user to choose RF input/output depending
on the operation frequency. The truth table of the GPIO 0-2 settings is shown below.

LMS6002D RF Input/output  |  GPIO 0  |  GPIO 1  |  GPIO 2  |  Description
--------------------------------------|------------- |-------------|--------------|-----------------
TX out 1  |  X   |  X  |   0   |  High band output (1500 – 3800 MHz)
TX out 2  |  X  |  X  |   1 |   Broadband output
Rx in 1  |  1 |  1  |   X  |  Low band input (300 – 2200 MHz)
Rx in 2  |  0 | 1 |  X |  High band input (1500-3800MHz)
Rx in 3  | 0  |   0  |  X |   Broadband input

Where:
X - don't care,
0 - logic low,
1  - logic high (3.3V for signal level).

Note: LMS6002D RF input/output have to be selected/programmed via SPI registers.

guruofquality, 2015-02-09:
Well if the switches are just for band selection, then there isnt much cause to automatically switch based on transmit state (consider a shared antenna in a half-duplex situation).

But still good to know for the host driver implementation... I will have to see how the lms-suite handles these IOs. Thanks for the information!

guruofquality, 2015-02-14:
Made hooks w/ antenna API to set these switches, we can make it automatic in the future:
https://github.com/myriadrf/Novena-RF/commit/44c31937edb4fa30837316ad0d2debb0711f8df2

Closed 2015-02-14.

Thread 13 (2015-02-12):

decimation/interpolation chain improvements

guruofquality, 2015-02-12:
I put in a chain of 4 half-bands for both interpolation and decimation by up to 1,2,4,8,or 16. Its not ideal:

* Every filter in the chain is identical (11 taps, clock rate/2), but we could save resources by allowing filters closer to baseband to work at lower rates, or have more taps for a better roll-off.
* The baseband samples could be scaled to compensate for filter gain/loss
* For a quick cheat to deal with output scaling, each filter's output is shifted up by 1. This factor of 2x matches the loss very closely, but large values could "clip" in a messy way.

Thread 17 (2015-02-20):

direct buffer access calls for RX and TX

guruofquality, 2015-02-20:
The API is almost complete: https://github.com/pothosware/SoapySDR/issues/8

This will give user's direct access to the DMA buffers, which will be a nice optimization when the FPGA sample format can be dealt with in the user's application --

TLDR: avoids data type conversion overhead.

guruofquality, 2015-02-22:
https://github.com/myriadrf/Novena-RF/commit/6b23e47064c9e3c8bbfb5c13f202346c6906a0fa

Closed 2015-02-22.

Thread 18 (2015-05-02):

lms-suite fails to build with libi2c-dev installed

rtongret, 2015-05-02:
Work around is to remove libi2c-dev and then compiling
$sudo apt-get remove libi2c-dev

----------------------------------
[  4%] Building CXX object CMakeFiles/NovenaRF.dir/home/ret/Novena-RF/lms-suite/lms-suite/src/src/ConnectionSPI.cpp.o
In file included from /home/ret/Novena-RF/lms-suite/lms-suite/src/src/ConnectionSPI.cpp:26:0:
/usr/include/linux/i2c-dev.h:37:8: error: redefinition of ‘struct i2c_msg’
 struct i2c_msg {
        ^
In file included from /home/ret/Novena-RF/lms-suite/lms-suite/src/src/ConnectionSPI.cpp:25:0:
/usr/include/linux/i2c.h:68:8: error: previous definition of ‘struct i2c_msg’
 struct i2c_msg {
        ^
In file included from /home/ret/Novena-RF/lms-suite/lms-suite/src/src/ConnectionSPI.cpp:26:0:
/usr/include/linux/i2c-dev.h:89:7: error: redefinition of ‘union i2c_smbus_data’
 union i2c_smbus_data {
       ^
In file included from /home/ret/Novena-RF/lms-suite/lms-suite/src/src/ConnectionSPI.cpp:25:0:
/usr/include/linux/i2c.h:128:7: error: previous definition of ‘union i2c_smbus_data’
 union i2c_smbus_data {
       ^
CMakeFiles/NovenaRF.dir/build.make:399: recipe for target 'CMakeFiles/NovenaRF.dir/home/ret/Novena-RF/lms-suite/lms-suite/src/src/ConnectionSPI.cpp.o' failed
make[2]: *** [CMakeFiles/NovenaRF.dir/home/ret/Novena-RF/lms-suite/lms-suite/src/src/ConnectionSPI.cpp.o] Error 1
CMakeFiles/Makefile2:60: recipe for target 'CMakeFiles/NovenaRF.dir/all' failed
make[1]: *** [CMakeFiles/NovenaRF.dir/all] Error 2
Makefile:127: recipe for target 'all' failed
make: *** [all] Error 2

guruofquality, 2015-05-05:
I think I saw this during development. It might just be a version mismatch between the kernel and the libi2c package. Anyway, the package removal seems to do the trick:

```
sudo apt-get remove libi2c-dev
Removing 'diversion of /usr/include/linux/i2c-dev.h to /usr/include/linux/i2c-dev.h.kernel by libi2c-dev'
```

I also added a note in the readme.

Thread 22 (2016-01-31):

error while building lms-suite

gasseralaaeldien, 2016-01-31:
Hi All,
while building lms-suite with this command :
'mkdir build && cd build && cmake .. && cmake --build .'
it outputs :

-- The C compiler identification is GNU 4.8.4
-- The CXX compiler identification is GNU 4.8.4
-- Check for working C compiler: /usr/bin/cc
-- Check for working C compiler: /usr/bin/cc -- works
-- Detecting C compiler ABI info
-- Detecting C compiler ABI info - done
-- Check for working CXX compiler: /usr/bin/c++
-- Check for working CXX compiler: /usr/bin/c++ -- works
-- Detecting CXX compiler ABI info
-- Detecting CXX compiler ABI info - done
-- Found wxWidgets: TRUE
-- Configuring done
-- Generating done
-- Build files have been written to: /home/gasser.alaaeldien/SVN/zigbee/lms-suite-master/lms-suite-master/LMS6002D/lms-suite/src/build
Scanning dependencies of target lms-suite
[  1%] Building CXX object CMakeFiles/lms-suite.dir/src/CommonUtilities.cpp.o
[  3%] Building CXX object CMakeFiles/lms-suite.dir/src/ConnectionCOM.cpp.o
/home/gasser.alaaeldien/SVN/zigbee/lms-suite-master/lms-suite-master/LMS6002D/lms-suite/src/src/ConnectionCOM.cpp:332:2: warning: #warning Currently searching only for ACM connections [-Wcpp]
 #warning Currently searching only for ACM connections
  ^
[  4%] Building CXX object CMakeFiles/lms-suite.dir/src/ConnectionManager.cpp.o
[  6%] Building CXX object CMakeFiles/lms-suite.dir/src/ConnectionSPI.cpp.o
/home/gasser.alaaeldien/SVN/zigbee/lms-suite-master/lms-suite-master/LMS6002D/lms-suite/src/src/ConnectionSPI.cpp: In function ‘bool IsNovenaBoard()’:
/home/gasser.alaaeldien/SVN/zigbee/lms-suite-master/lms-suite-master/LMS6002D/lms-suite/src/src/ConnectionSPI.cpp:40:30: error: elements of array ‘i2c_msg messages [2]’ have incomplete type
     struct i2c_msg messages[2];
                              ^
/home/gasser.alaaeldien/SVN/zigbee/lms-suite-master/lms-suite-master/LMS6002D/lms-suite/src/src/ConnectionSPI.cpp:40:30: error: storage size of ‘messages’ isn’t known
/home/gasser.alaaeldien/SVN/zigbee/lms-suite-master/lms-suite-master/LMS6002D/lms-suite/src/src/ConnectionSPI.cpp:51:25: error: ‘I2C_M_RD’ was not declared in this scope
     messages[1].flags = I2C_M_RD;
                         ^
make[2]: *** [CMakeFiles/lms-suite.dir/src/ConnectionSPI.cpp.o] Error 1
make[1]: *** [CMakeFiles/lms-suite.dir/all] Error 2
make: *** [all] Error 2

i don't know what is wrong

guruofquality, 2016-01-31:
There is an i2c dev package that seems to interfere. Does this command in the readme fix it?
https://github.com/myriadrf/Novena-RF/blob/master/driver/README.md#dependencies

gasseralaaeldien, 2016-02-01:
i run these two lines :
sudo apt-get install cmake g++ libusb-1.0-0-dev git
sudo apt-get remove libi2c-dev #fixes build issue

but it still gives me the same error

guruofquality, 2016-02-03:
I know it sounds funny, but if libi2c-dev was not originally installed does ```sudo apt-get install libi2c-dev``` install fix it? (this has been the case on ubuntu for example)

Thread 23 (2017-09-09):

Compiling issue at make step

janemba, 2017-09-09:
hi,

I have an error compiling Novena-FR, at make step I have the following error:

    $ make
    Scanning dependencies of target NovenaRF
    [  4%] Building CXX object CMakeFiles/NovenaRF.dir/Streaming.cpp.o
    In file included from /usr/include/features.h:392:0,
                     from /usr/include/c++/5.3.1/arm-slackware-linux-gnueabi/bits/os_defines.h:39,
                     from /usr/include/c++/5.3.1/arm-slackware-linux-gnueabi/bits/c++config.h:482,
                     from /usr/include/c++/5.3.1/cstdint:38,
                     from /tmp/Novena-RF/driver/host/NovenaRegs.hpp:11,
                     from /tmp/Novena-RF/driver/host/NovenaRF.hpp:11,
                     from /tmp/Novena-RF/driver/host/Streaming.cpp:10:
    /usr/include/gnu/stubs.h:10:29: fatal error: gnu/stubs-hard.h: No such file or directory
    compilation terminated.
    CMakeFiles/NovenaRF.dir/build.make:62: recipe for target          CMakeFiles/NovenaRF.dir/Streaming.cpp.o' failed
    make[2]: *** [CMakeFiles/NovenaRF.dir/Streaming.cpp.o] Error 1
    CMakeFiles/Makefile2:67: recipe for target 'CMakeFiles/NovenaRF.dir/all' failed
    make[1]: *** [CMakeFiles/NovenaRF.dir/all] Error 2
    Makefile:138: recipe for target 'all' failed
    make: *** [all] Error 2

Do you know how can I fix this ?

(I'm compiling natively on Novena).

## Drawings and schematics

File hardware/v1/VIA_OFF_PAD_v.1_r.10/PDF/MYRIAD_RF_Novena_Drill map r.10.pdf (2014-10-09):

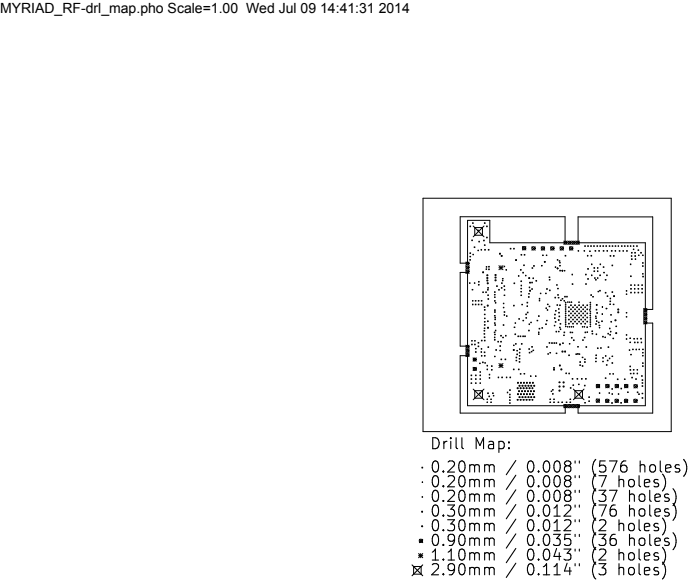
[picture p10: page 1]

MYRIAD_RF-drl_map.pho Scale=1.00 Wed Jul 09 14:41:31 2014

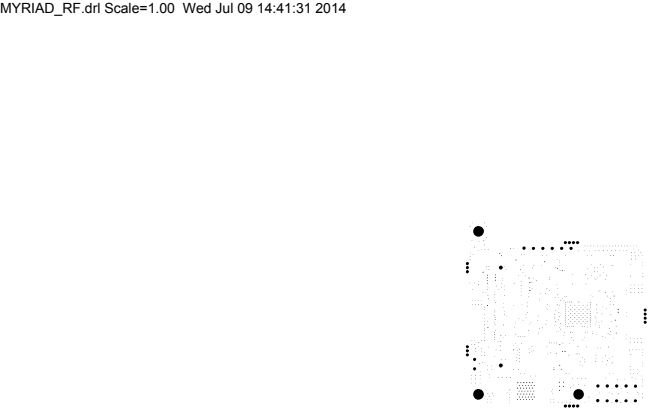
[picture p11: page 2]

MYRIAD_RF.drl Scale=1.00 Wed Jul 09 14:41:31 2014

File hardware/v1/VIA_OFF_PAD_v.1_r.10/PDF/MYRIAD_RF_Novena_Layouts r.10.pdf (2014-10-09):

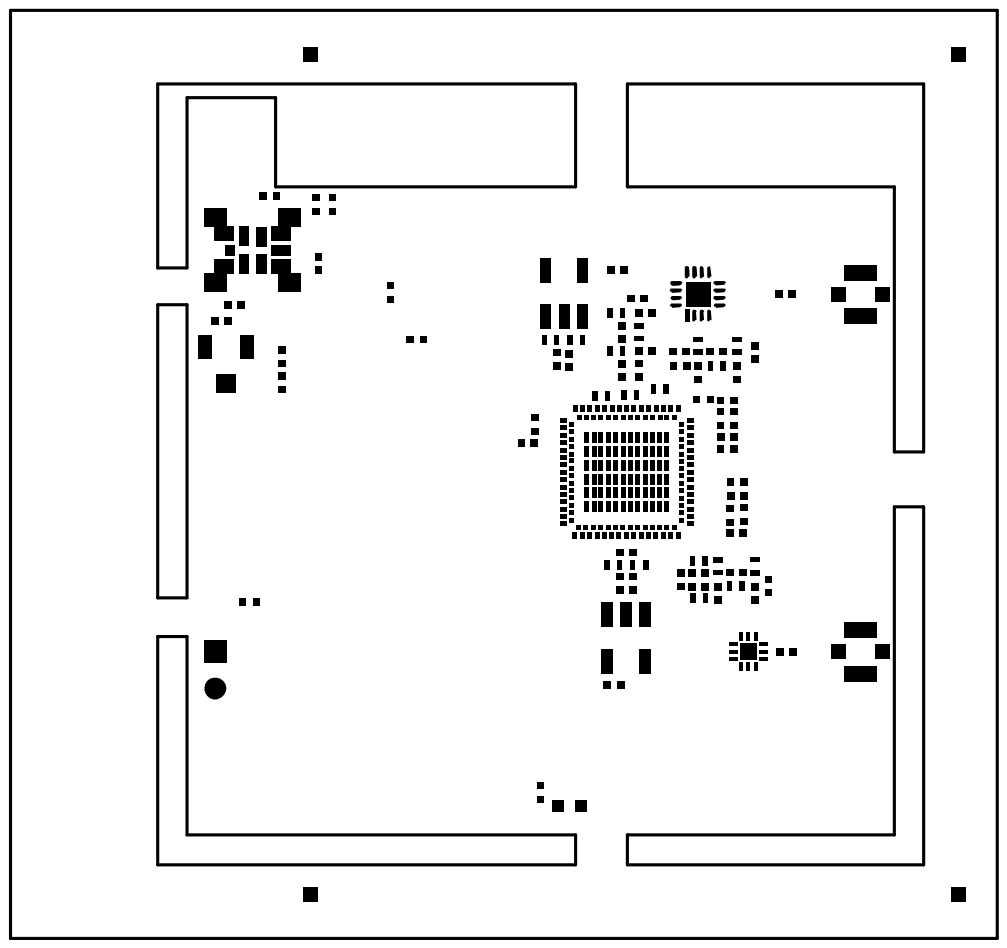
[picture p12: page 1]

MYRIAD_RF-F_Paste.gtp Scale=1.00 Wed Jul 09 14:38:26 2014

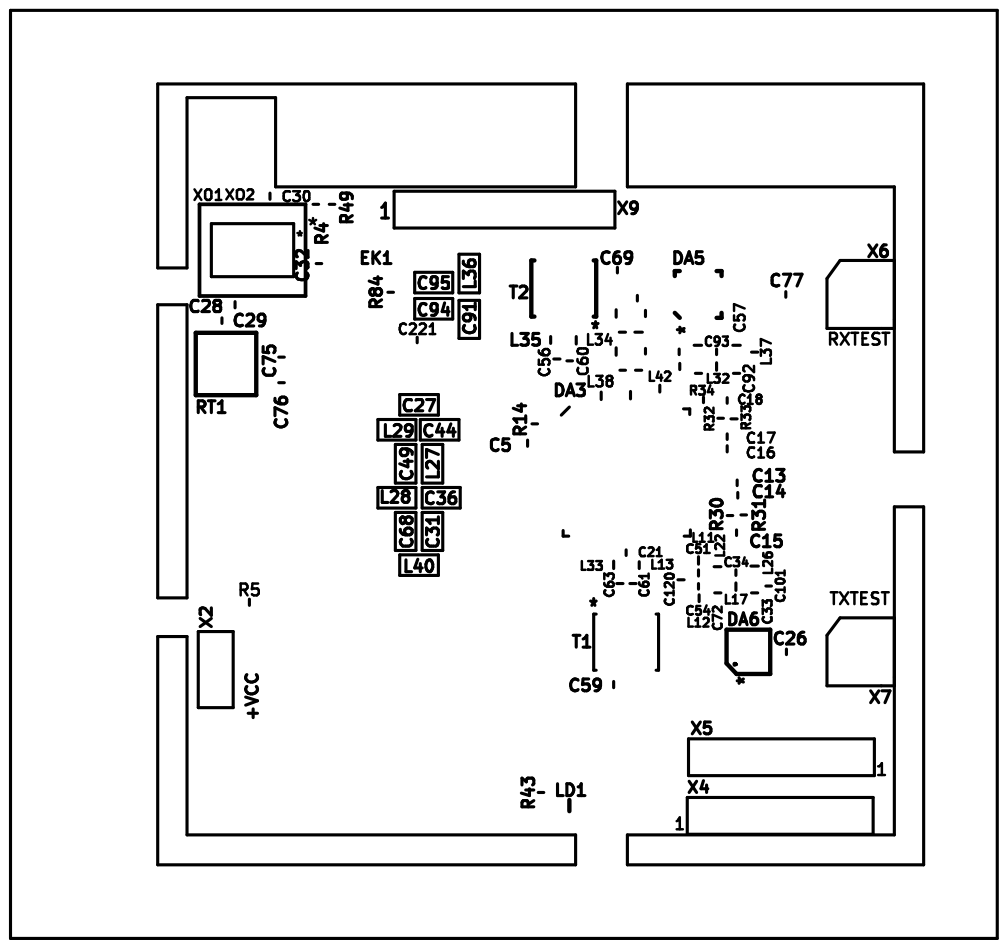
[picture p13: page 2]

MYRIAD_RF-F_SilkS.gto Scale=1.00 Wed Jul 09 14:38:26 2014

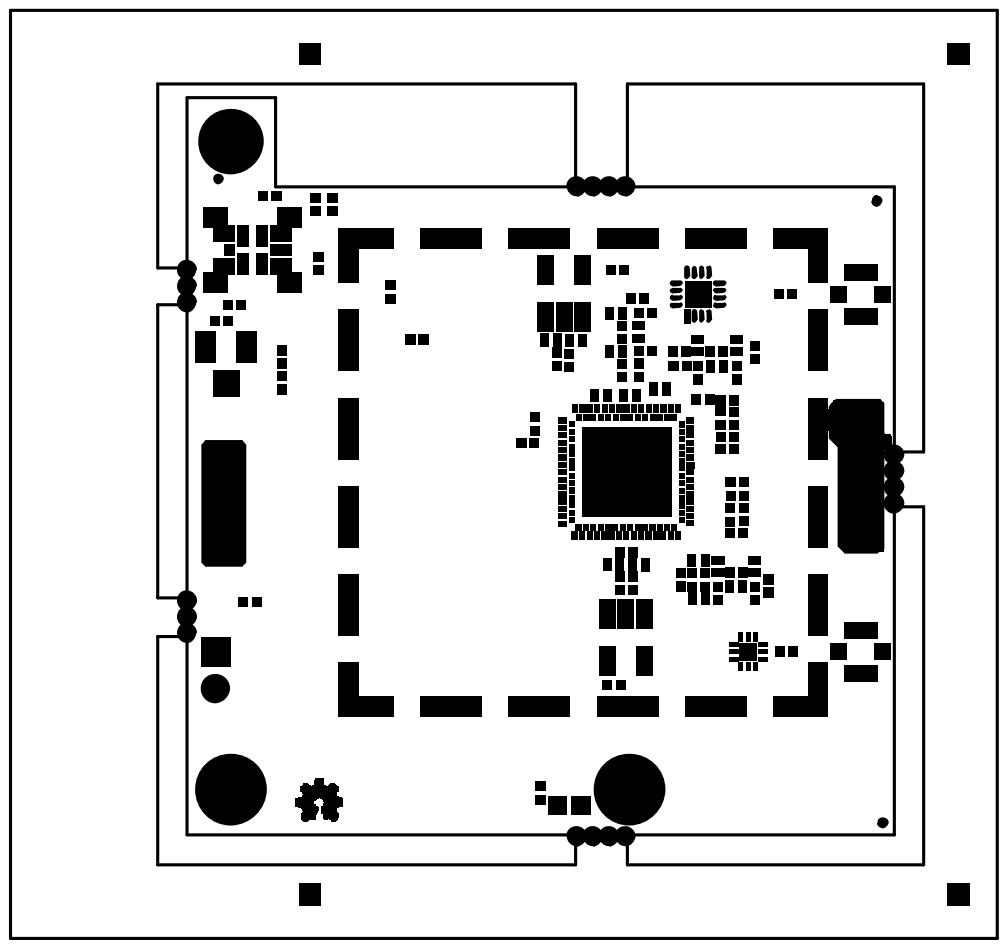
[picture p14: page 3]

MYRIAD_RF-F_Mask.gts Scale=1.00 Wed Jul 09 14:38:26 2014

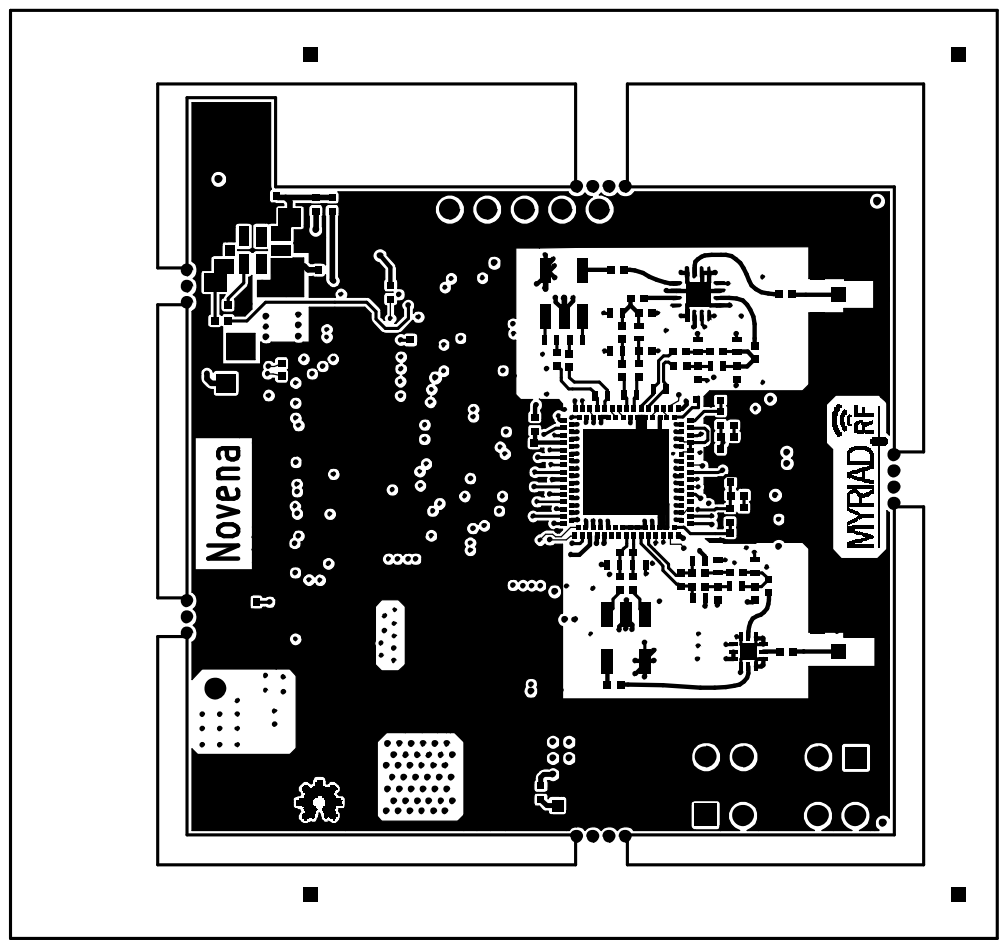
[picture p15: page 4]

MYRIAD_RF-Front.gtl Scale=1.00 Wed Jul 09 14:38:26 2014

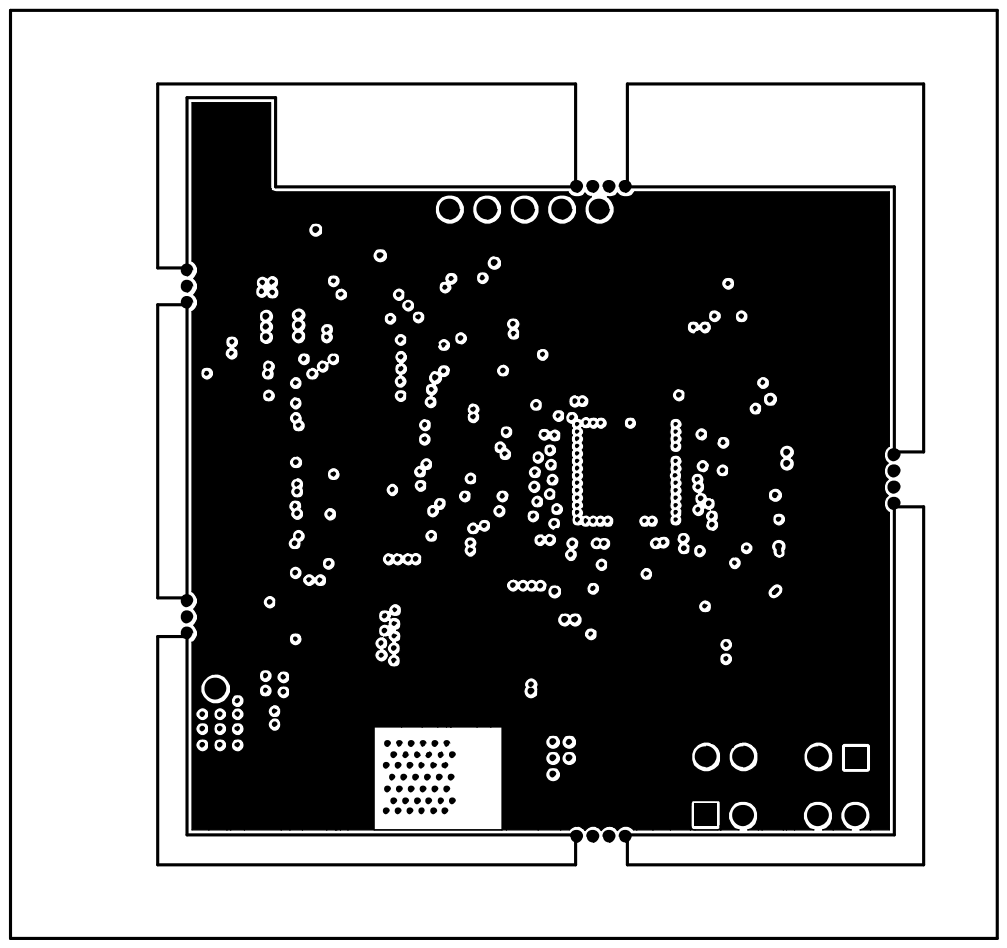
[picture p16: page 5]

MYRIAD_RF-Inner_GND.gbr Scale=1.00 Wed Jul 09 14:38:27 2014

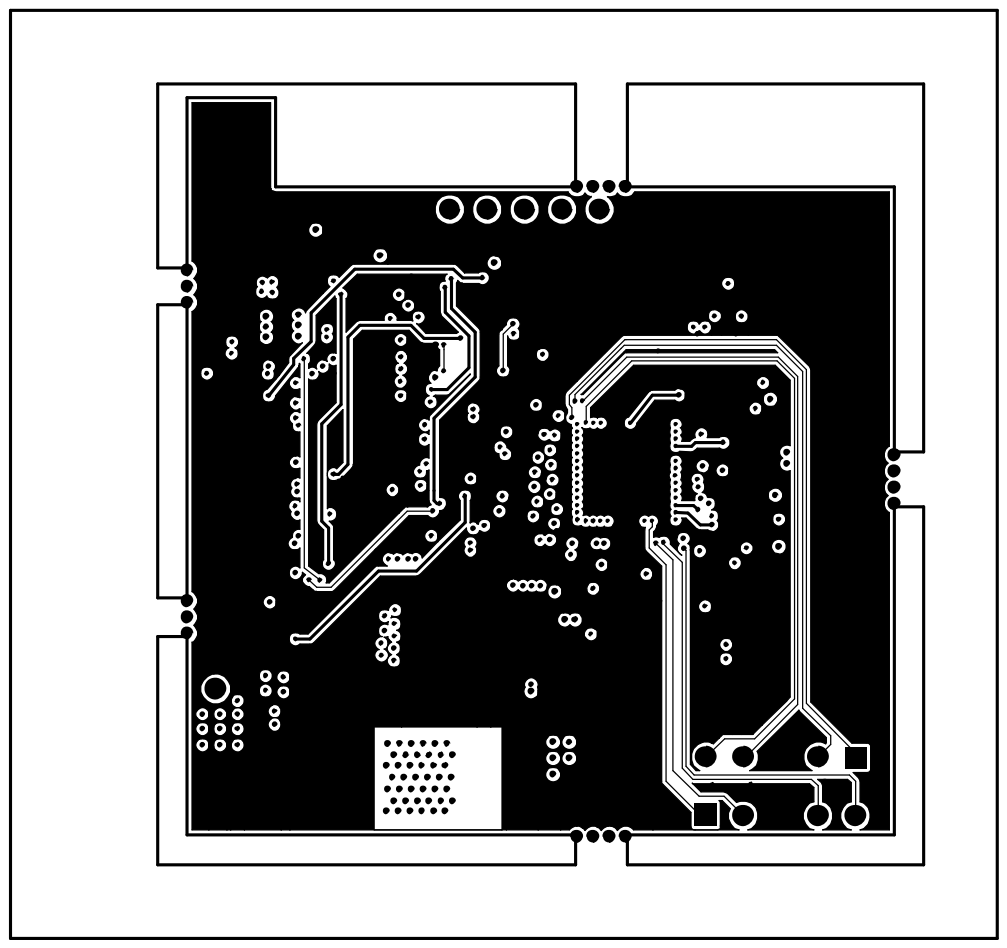
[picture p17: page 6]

MYRIAD_RF-Inner_Analog_Signal.gbr Scale=1.00 Wed Jul 09 14:38:27 2014

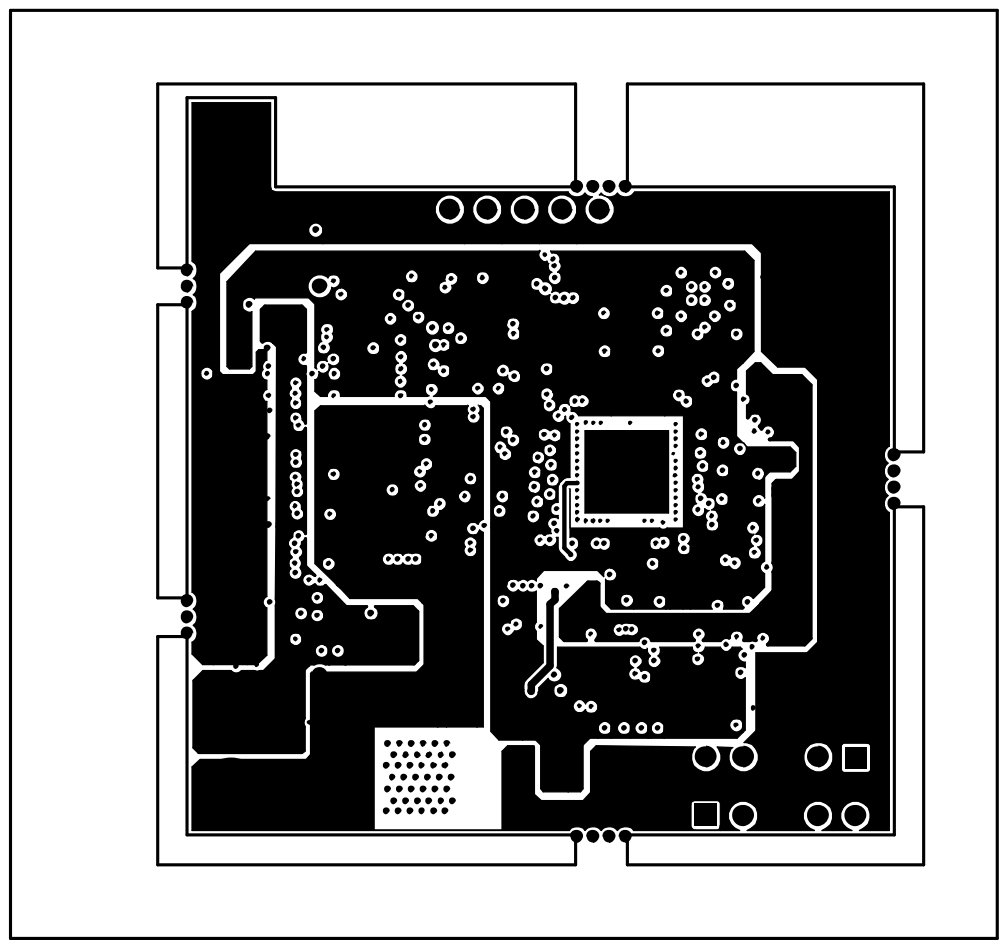
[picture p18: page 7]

MYRIAD_RF-Inner_Power.gbr Scale=1.00 Wed Jul 09 14:38:27 2014

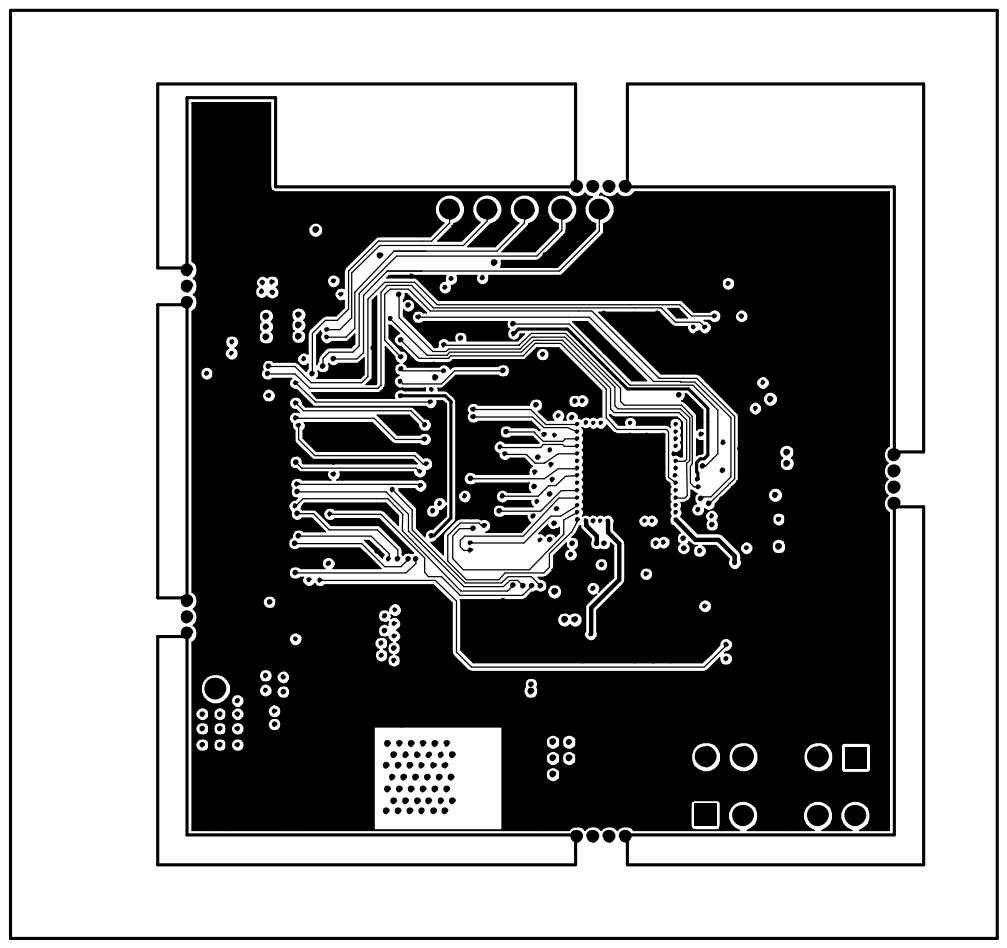
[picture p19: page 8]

MYRIAD_RF-Inner_Digital_Signal.gbr Scale=1.00 Wed Jul 09 14:38:27 2014

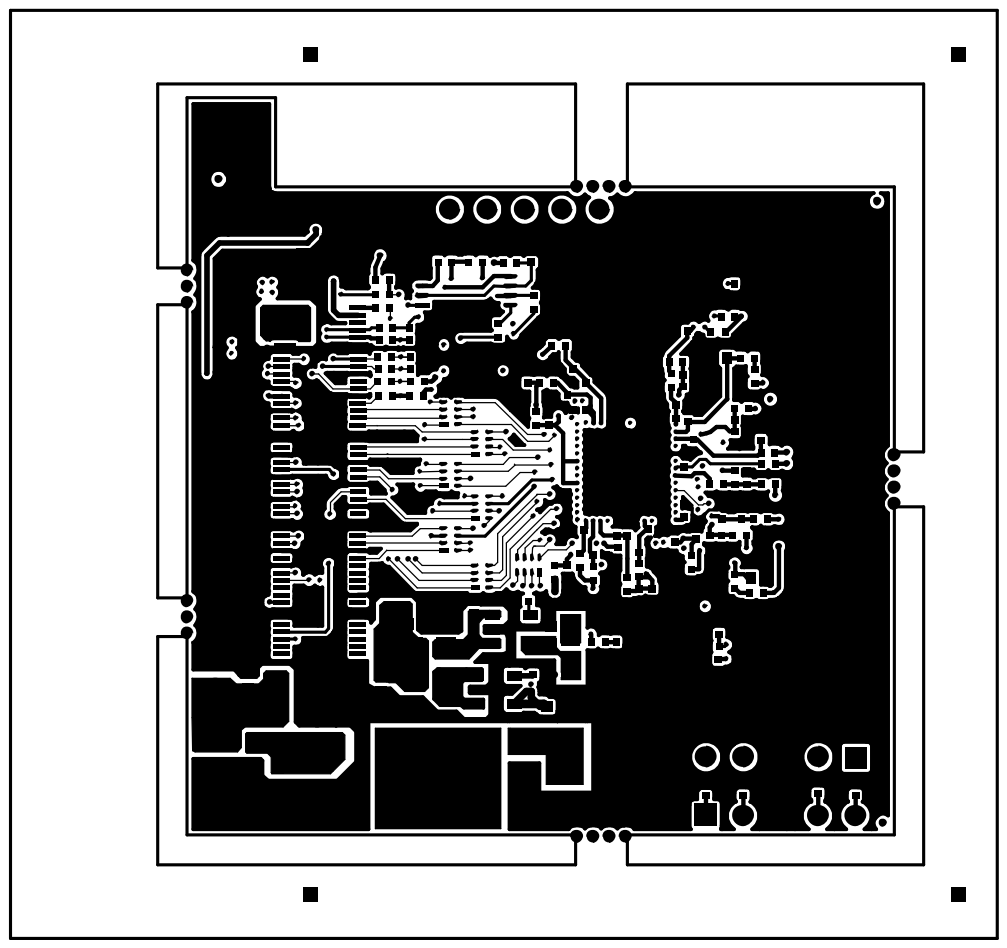
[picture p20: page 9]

MYRIAD_RF-Back.gbl Scale=1.00 Wed Jul 09 14:38:27 2014

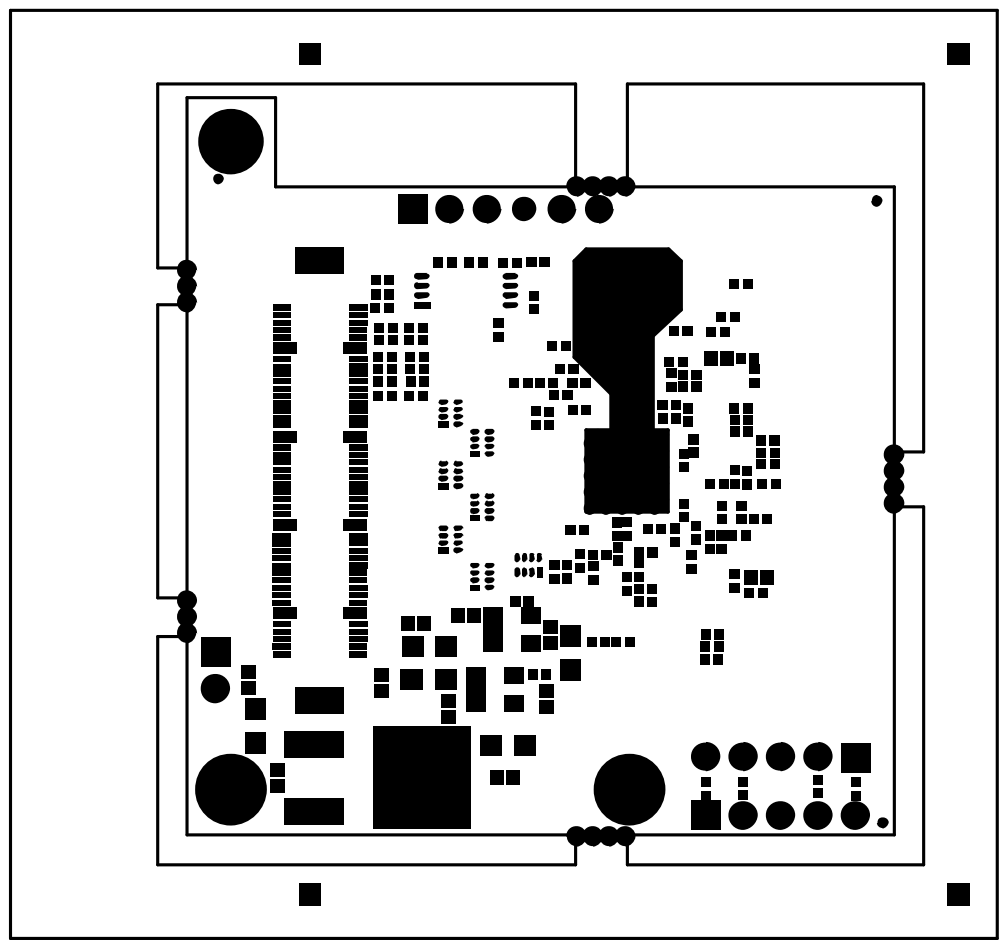
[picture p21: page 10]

MYRIAD_RF-B_Mask.gbs Scale=1.00 Wed Jul 09 14:38:27 2014


MYRIAD_RF-B_SilkS.gbo Scale=1.00 Wed Jul 09 14:38:27 2014


MYRIAD_RF-B_Paste.gbp Scale=1.00 Wed Jul 09 14:38:27 2014


MYRIAD_RF-Edge_Cuts.gbr Scale=1.00 Wed Jul 09 14:38:27 2014


MYRIAD_RF-Dwgs_User.gbr Scale=1.00 Wed Jul 09 14:38:27 2014








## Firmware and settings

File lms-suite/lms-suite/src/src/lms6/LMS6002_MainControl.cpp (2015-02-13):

/**
@file   LMS6002_MainControl.cpp
@author Lime Microsystems (www.limemicro.com)
@brief  Main functions for controlling LMS6002 chip
*/

#include "LMS6002_MainControl.h"
#include "ConnectionManager.h"
#include "RegistersMap.h"
#include "Algorithms.h"
//#include "MessageLog.h"
#include "CommonUtilities.h"
#include <math.h>
#include <sstream>
#include <iomanip>
#include "iniParser.h"
#include "Si5351C.h"
#include "Si5356A.h"
#include "ADF_module.h"
using namespace std;
namespace lms6
{

/** @brief changes index value to SELVCO acctual value
    @param i index
    (0:all powered down, 1:lowFreq, 2:midLowFreq, 3:midHighFreq, 4:highFreq)
    (0:all powered down, 1:Fvco/2, 2:Fvco/4, 3:Fvco/8, 4:Fvco/16)
    @return SELVCO value
*/
int indexToSELVCO_FRANGE(int i)
{
    switch(i)
    {
    case 0:
        return 0;
    case 1:
        return 4;
    case 2:
        return 5;
    case 3:
        return 6;
    case 4:
        return 7;
    default:
        return 0;
    }
}

/** @brief Changes SELVCO and FRANGE values to index value
    @param value SELVCO or FRANGE value
    @return index
*/
int SELVCO_FRANGE_ToIndex(int value)
{
    switch(value)
    {
    case 0:
        return 0;
    case 4:
        return 1;
    case 5:
        return 2;
    case 6:
        return 3;
    case 7:
        return 4;
    default:
        return 0;
    }
}

/** @brief Handles incoming messages
    @param msg message about event
*/
void LMS6002_MainControl::HandleMessage(const LMS_Message &msg)
{
    //currently just relay all incoming messages to main control listeners
    if(msg.type == MSG_REGISTER_TEST)
    {
        //MessageLog::getInstance()->write(msg.text, LOG_INFO);
    }
    Notify(msg);
}

/** @brief Creates and initializes control modules and registers map
*/
LMS6002_MainControl::LMS6002_MainControl(ConnectionManager* serPort)
{
    if(serPort == NULL)
        printf("LMS6002 MainControl: connection manager is NULL\n");
    m_device = serPort;
    m_GPIO = 0;
    algorithms = new Algorithms(this);
    //default reference frequency
    m_FreqRx_MHz = 2199;
    m_FreqTx_MHz = 2200;
    m_registersMap = new RegistersMap(m_device);

    Initialize();
    LoadAdditionalSettings();

    //listen for events from device manager
    m_device->RegisterForNotifications(this);
}

/** @brief Initializes control modules
*/
void LMS6002_MainControl::Initialize()
{
    LMS_Message msg;
    msg.text = "LMS6002 Main control initialized\n";
    msg.type = MSG_INFO;
    Notify(msg);
}

/** @brief Deletes all control modules
*/
LMS6002_MainControl::~LMS6002_MainControl()
{
    m_device->UnregisterFromNotifications(this);
    delete algorithms;
    delete m_device;
}

/** @brief Loads register values from file
    @param filename file to load
    @return true if success
*/
bool LMS6002_MainControl::LoadFromFile(const char *filename)
{
    bool status = false;
    bool loadFromBinary = false;
    char temp[128];
    ifstream fin;
    fin.open(filename, ios::in | ios::binary);

    memset(temp,0,128);
    fin.read( temp, 7);
    if(strcmp(temp, "LMS6002") == 0) //check if file type is binary
        loadFromBinary = true;

    if(loadFromBinary)
    {
        fin.seekg(0, ios::beg); // reset to file beginning
        status = m_registersMap->LoadFromStream(fin);
        fin.read(temp, 12);
    }
    fin.close();

    if(!loadFromBinary)
    {
        bool autoUploadState = GetAutoUpload();
        SetAutoUpload(false);
        iniParser parser;
        parser.Open(filename);
        parser.SelectSection("FILE INFO");
        string type = "";
        type = parser.Get("type", "undefined");
        stringstream ss;
        if(type != "LMS6002 configuration")
        {
            ss << "File " << filename << " not recognized" << endl;
            //MessageLog::getInstance()->write(ss.str(), LOG_ERROR);
            Notify( LMS_Message(MSG_ERROR, ss.str(), 0, 0) );
            return false;
        }

        int fileVersion = 0;
        fileVersion = parser.Get("version", 0);

        if(fileVersion == 1)
        {
            map<string, string>::iterator pairs;
            parser.SelectSection("LMS6002 registers");
            map<string, string> regValues = parser.GetCurrentSection();

            unsigned int addr = 0;
            unsigned int value = 0;
            for(pairs = regValues.begin(); pairs != regValues.end(); ++pairs)
            {
                sscanf(pairs->first.c_str(), "%x", &addr);
                sscanf(pairs->second.c_str(), "%x", &value);
                m_registersMap->SetRegisterValue(addr, value);
            }

            parser.SelectSection("Frequencies");
            m_FreqTx_MHz = parser.Get("FreqTx_MHz", 2.14);
            m_FreqRx_MHz = parser.Get("FreqRx_MHz", 2.13);

            parser.SelectSection("Reference clocks");
            double refClk;
            refClk = parser.Get("Tx reference clock MHz", 30.72);
            SetReferenceFrequency(refClk, false);
            refClk = parser.Get("Rx reference clock MHz", 30.72);
            SetReferenceFrequency(refClk, true);
        }
        SetAutoUpload(autoUploadState);
        status = true;
    }

    return status;
}

/** @brief Saves register values to file
    @param filename file to save into
    @param binary binary or text file
    @return true if success
*/
bool LMS6002_MainControl::SaveToFile(const char *filename, bool binary)
{
    bool status = false;
    if(binary)
    {
        return false;
        //status = m_registersMap->SaveToFile(filename, binary);
        ofstream fout;
        fout.open(filename, ios::out | ios::binary);
        m_registersMap->SaveToStream(fout);
        fout.close();
    }
    else
    {
        iniParser parser;
        parser.SelectSection("FILE INFO");
        parser.Set("type", "LMS6002 configuration");
        parser.Set("version", 1);

        map<valType, Register>::iterator pairs;
        pairs = getRegistersMap()->m_registers.begin();
        parser.SelectSection("LMS6002 registers");

        char addr[80];
        char value[80];

        for(pairs = getRegistersMap()->m_registers.begin(); pairs != getRegistersMap()->m_registers.end(); ++pairs)
        {
            sprintf(addr, "0x%02X", pairs->first);
            sprintf(value, "0x%02X", pairs->second.value);
            parser.Set(addr,value);
        }

        parser.SelectSection("Frequencies");
        parser.Set("FreqTx_MHz", m_FreqTx_MHz);
        parser.Set("FreqRx_MHz", m_FreqRx_MHz);

        parser.SelectSection("Reference clocks");
        double refClk = 0;
        refClk = GetReferenceFrequency(false);
        parser.Set("Tx reference clock MHz", refClk);
        refClk = GetReferenceFrequency(false);
        parser.Set("Rx reference clock MHz", refClk);

        parser.Save(filename);
        status = true;
    }
    return status;
}

/** @brief Discovers all connected chips
*/
void LMS6002_MainControl::FindDevices()
{
    m_device->FindDevices();
}

/** @brief Sends reset signal to chip
    @param action Reset type
        0 - deactivate reset
        1 - activate reset
        2 - pulse reset
    @return 1 : success
            0 : failure
            -1 : board not connected

*/
int LMS6002_MainControl::ResetChip(int action)
{
    LMS_Message msg;
    if(m_device->IsOpen() == false)
    {
        msg.text = "Reset: board not connected\n";
        msg.type = MSG_ERROR;
        Notify(msg);
        return -1;
    }
    GenericPacket pkt;
    pkt.cmd = CMD_LMS6002_RST;
    pkt.outBuffer[0] = action;
    pkt.outLen = 1;
    if( m_device->TransferPacket(pkt) == STATUS_COMPLETED_CMD )
    {
        switch(action)
        {
        case LMS_RST_DEACTIVATE:
            msg.text = "Chip Reset deactivated\n";
            break;
        case LMS_RST_ACTIVATE:
            msg.text = "Chip Reset activated\n";
            break;
        case LMS_RST_PULSE:
            msg.text = "Chip Reset pulse\n";
            break;
        default:
            msg.text = "Unknown reset type (available types: deactivate, activate, pulse)\n";
            msg.type = MSG_ERROR;
            Notify(msg);
            return 0;
        }
        //MessageLog::getInstance()->write(msg.text, LOG_INFO);
        msg.type = MSG_INFO;
        Notify(msg);
        return 1;
    }
    msg.text = "Failed to change reset state\n";
    msg.type = MSG_WARNING;
    Notify(msg);
    return 0;
}

/** @brief Sends all configuration to the chip
    @return true if success
*/
bool LMS6002_MainControl::UploadAll()
{
    LMS_Message msg;
    int status = m_registersMap->UploadAll();
    //set pa and lna, to update gpio values
    SetParam(PA_EN, GetParam(PA_EN));
    SetParam(LNASEL_RXFE, GetParam(LNASEL_RXFE));
    if(status == 1)
    {
        msg.type = MSG_INFO;
        msg.text = "Uploaded all configuration\n";
        return true;
    }
    else
    {
        if(status == 0)
        {
            msg.type = MSG_ERROR;
            msg.text = "Failed to upload all configuration\n";
        }
        else if(status == -1)
        {
            msg.type = MSG_WARNING;
            msg.text = "Board not connected\n";
        }
        return false;
    }
}

/** @brief Reads all configuration from the chip
    @return true if success
*/
bool LMS6002_MainControl::DownloadAll()
{
    LMS_Message msg;
    int status = m_registersMap->DownloadAll();
    if(status == 1)
    {
        msg.type = MSG_INFO;
        msg.text = "Downloaded all configuration\n";
        return true;
    }
    else
    {
        if(status == 0)
        {
            msg.type = MSG_ERROR;
            msg.text = "Failed to download all configuration\n";
        }
        else if(status == -1)
        {
            msg.type = MSG_WARNING;
            msg.text = "Board not connected\n";
        }
        return false;
    }
}

/** @brief Set chosen parameter to given value
    @param param LMS7002 parameter
    @param value new parameter value
    @return true if success
*/
bool LMS6002_MainControl::SetParam(LMS_Parameter param, const long value)
{
    int N; double intFvco;
    bool status = m_registersMap->SetParameterValue(param, value);
    if(param == ACODE_RXPLL || param == BCODE_RXPLL)
        CalcIntPllData(true, intFvco, N);
    else if(param == ACODE_TXPLL || param == BCODE_TXPLL)
        CalcIntPllData(false, intFvco, N);
    else if(param == STXEN)
        m_registersMap->SetParameterValue(CLK_EN_0, value > 0);
    else if(param == SRXEN)
        m_registersMap->SetParameterValue(CLK_EN_2, value > 0);
    else if(param == LNASEL_RXFE)
    {
        m_registersMap->SetParameterValue(SELOUT_RXPLL, value);
        unsigned char buf[1];
        switch(value)
        {
            case 1:
                buf[0] = 0x03;
                break;
            case 2:
                buf[0] = 0x01;
                break;
            case 3:
                buf[0] = 0x00;
                break;
            default:
                buf[0] = 0x03;
                break;
        }
        GenericPacket pkt;
        if(m_device->GetExpansionBoardType() != EXP_BOARD_HPM1000)
        {
            if(m_device->GetConnectedDeviceType() == LMS_DEV_ZIPPER)
                SetGPIO(1, 0, buf[0]);
            else
            {
                pkt.cmd = CMD_LMS_LNA;
                pkt.outLen = 1;
                pkt.outBuffer[0] = buf[0];
                m_device->TransferPacket(pkt);
            }
        }
    }
    else if(param == PA_EN)
    {
        unsigned char buf[1];
        switch(value)
        {
            case 1:
                buf[0] = 0x00;
                break;
            case 2:
                buf[0] = 0x01;
                break;
            default:
                buf[0] = 0;
                break;
        }

        if(m_device->GetExpansionBoardType() != EXP_BOARD_HPM1000)
        {
            if(m_device->GetConnectedDeviceType() == LMS_DEV_ZIPPER)
                SetGPIO(2, 2, buf[0]);
            else
            {
                GenericPacket pkt;
                pkt.cmd = CMD_LMS_PA;
                pkt.outLen = 1;
                pkt.outBuffer[0] = buf[0];
                m_device->TransferPacket(pkt);
            }
        }
    }
    return status;
}

/** @brief Returns value of chosen parameter
    @param param LMS7002 parameter
    @return parameter value
*/
long LMS6002_MainControl::GetParam(LMS_Parameter param, const bool fromChip, const bool updateLocal) const
{
    return m_registersMap->GetParameterValue(param, fromChip, updateLocal);
}

RegistersMap* LMS6002_MainControl::getRegistersMap() const
{
    return m_registersMap;
}

ConnectionManager* LMS6002_MainControl::getSerPort() const
{
    return m_device;
}

/** @brief Enables or disables auto download mode
    @param enabled auto download enable
    When auto download is enabled each GetParam() call will read register value
    from chip, otherwise the returned value will be from local program memory
*/
void LMS6002_MainControl::SetAutoDownload(const bool enabled)
{
    m_registersMap->SetAutoDownload(enabled);
}

/** @brief Returns auto download state
    @return auto download enabled
*/
bool LMS6002_MainControl::GetAutoDownload() const
{
    return m_registersMap->GetAutoDownload();
}

/** @brief Enables or disables auto uploading
    @param enabled auto upload enable
    When auto upload is enabled each SetParam call will write register value to
    the chip, otherwise value is written to local memory for later writing.
*/
void LMS6002_MainControl::SetAutoUpload(const bool enabled)
{
    m_registersMap->SetAutoUpload(enabled);
}

/** @brief Returns auto upload state
    @return auto upload enabled
*/
bool LMS6002_MainControl::GetAutoUpload() const
{
    return m_registersMap->GetAutoUpload();
}

/** @brief Sets reference frequency
    @param freq_MHz reference frequency in MHz
    @param Rx true for receiver, false for transmitter
    @return true if success
*/
bool LMS6002_MainControl::SetReferenceFrequency(const double freq_MHz, const bool Rx)
{
    if(Rx)
        m_RxPLL.SetReferenceFrequency(freq_MHz);
    else
        m_TxPLL.SetReferenceFrequency(freq_MHz);
    return true;
}

/** @brief Returns reference frequency
    @param Rx true for receiver, false for transmitter
    @return reference frequency in MHz
*/
double LMS6002_MainControl::GetReferenceFrequency(const bool Rx) const
{
    if(Rx)
        return m_RxPLL.GetReferenceFrequency();
    else
        return m_TxPLL.GetReferenceFrequency();
}

/** @brief Sets transmitter or receiver to desired frequency and returns configuration values
    @param Rx true for receiver, false for transmitter
    @param desFreq_MHz desired frequency in MHz
    @param realFreq_MHz frequency that was set
    @param iVCO VCO index
    @param fVCO VCO frequency in MHz
    @return
    - -1 cannot deliver requested frequency
    - 0 success
    - 1 requested frequency out of range. Set to closest available frequency
*/
int LMS6002_MainControl::SetFrequency(const bool Rx, const double desFreq_MHz, double &realFreq_MHz, unsigned &Nint, unsigned &Nfrac, unsigned &iVCO, double &Fvco_MHz, int &Divider)
{
	int iCap;
    int status = 0;

    PLL* pll = NULL;
    if(Rx)
        pll = &m_RxPLL;
    else
        pll = &m_TxPLL;

    status = pll->FreqParams(desFreq_MHz, realFreq_MHz, Nint, Nfrac, iVCO, Fvco_MHz, Divider);
    if(status == -1) //can't deliver frequency
    {
        LMS_Message msg;
        msg.type = MSG_ERROR;
        stringstream ss;
        ss << (Rx ? "Rx:":"Tx:") << " Cannot deliver requested frequency (" << desFreq_MHz << " MHz)\n";
        msg.text = ss.str();
        Notify(msg);
        return status;
    }

	if(Rx)
        m_FreqRx_MHz = desFreq_MHz;
    else
        m_FreqTx_MHz = desFreq_MHz;

	SetParam(Rx ? FRANGE_RXPLL : FRANGE_TXPLL, indexToSELVCO_FRANGE(Divider));
    SetParam(Rx ? NINT_RXPLL : NINT_TXPLL, Nint);
	SetParam(Rx ? NFRAC_RXPLL : NFRAC_TXPLL, Nfrac);
	SetParam(Rx ? SELVCO_RXPLL : SELVCO_TXPLL, indexToSELVCO_FRANGE(iVCO));

    iCap = pll->AutoSelectVcoCap(Fvco_MHz, iVCO);

	if ((iCap > 61) && ((iVCO == 2) || (iVCO == 3) || (iVCO == 4)))
	{
		iVCO--;
        iCap = pll->AutoSelectVcoCap(Fvco_MHz, iVCO);
	};
	SetParam(Rx ? VCOCAP_RXPLL : VCOCAP_TXPLL, iCap);
    int N;
    double intFvco;
	CalcIntPllData(Rx, intFvco, N);

    LMS_Message msg;
    stringstream ss;
	if(status == 1)
    {
        msg.type = MSG_WARNING;
        ss << (Rx ? "Rx:":"Tx:") << " Requested frequency(" << desFreq_MHz << " MHz) is out of range. Configuring to closest available frequency\n";
    }
    else
    {
        msg.type = MSG_INFO;
        ss << (Rx ? "Rx:":"Tx:") << " Frequency set to " << realFreq_MHz << " MHz\n";
    }
    msg.text = ss.str();
    Notify(msg);
	return status;
}

/** @brief Returns frequency of transmitter or receiver
    @param Rx true for receiver, false for transmitter
    @return Frequency in MHz
*/
double LMS6002_MainControl::GetFrequency(const bool Rx) const
{
    if(Rx)
        return m_FreqRx_MHz;
    else
        return m_FreqTx_MHz;
}

/** @brief Tunes transmitter or receiver
    @param Rx true for receiver, false for transmitter
    @return 0 : failure
            1 : success
*/
int LMS6002_MainControl::Tune(const bool Rx)
{
    if(m_device->IsOpen() == false)
    {
        Notify( LMS_Message(MSG_ERROR, "Tune: Board not connected\n", 0, 0) );
        return 0;
    }
    int iCap00;
	int iCap63;
	int iInitCap;
	int iInitVco;

	// Remember the initial states of CAP and VCO
	iInitCap = GetParam(Rx ? VCOCAP_RXPLL : VCOCAP_TXPLL, true, true);
	iInitVco = SELVCO_FRANGE_ToIndex(GetParam(Rx ? SELVCO_RXPLL : SELVCO_TXPLL, true, true));

	for (int i = 1; i <= 4; i++)
	{
		stringstream Str;
		Str << "=== Trying VCO Nr. ";
		Str << (5 - i);
		Str << " ===" << endl;
		Notify( LMS_Message(MSG_INFO, Str.str(), 0, 0) );
		Str.str("");

		// Choose VCO
		SetParam(Rx ? SELVCO_RXPLL : SELVCO_TXPLL, indexToSELVCO_FRANGE(i));

		// Set CAP to '0'
		SetParam(Rx ? VCOCAP_RXPLL : VCOCAP_TXPLL, 0);

		// See what the values of Vh and Vl are
		int vh = GetParam(Rx?VTUNE_H_RXPLL:VTUNE_H_TXPLL, true, true);
		int vl = GetParam(Rx?VTUNE_L_RXPLL:VTUNE_L_TXPLL); //gets updated when reading VTUNE_H
		iCap00 = vh << 1 | vl;

		// Set CAP to '63'
        SetParam(Rx ? VCOCAP_RXPLL : VCOCAP_TXPLL, 63);
		// See what are the values of Vh and Vl
		vh = GetParam(Rx?VTUNE_H_RXPLL:VTUNE_H_TXPLL, true, true);
		vl = GetParam(Rx?VTUNE_L_RXPLL:VTUNE_L_TXPLL, true);
		iCap63 = vh << 1 | vl;

		Str << "Vtune for CAP=0 is ";
		Str << iCap00 << endl;
		Str << "Vtune for CAP=63 is ";
		Str << iCap63 << endl;
		Notify( LMS_Message(MSG_INFO, Str.str(), 0, 0) );
		Str.str("");

		if (( SELVCO_FRANGE_ToIndex(GetParam(Rx?SELVCO_RXPLL:SELVCO_TXPLL, true, true)) == 4) && (iCap00 == 0x02) && (iCap63 == 0x02))
		{
			break;
		};

		if ((iCap00 == 0x02) && (iCap63 == 0x01))
		{
			Notify( LMS_Message(MSG_INFO, "VCO can deliver required frequency.\n", 0, 0) );
			//Notify( LMS_Message(MSG_INFO, "Starting Procedure.\n", 0, 0) );

			// Set CAP in the middle of the range
			SetParam(Rx ? VCOCAP_RXPLL : VCOCAP_TXPLL, 31);

			// Try to Tune
			algorithms->CapAutoTune_S(Rx);

			Str << "Selected CAP = ";
			Str << GetParam(Rx ? VCOCAP_RXPLL : VCOCAP_TXPLL, true, true) << endl;
			Notify( LMS_Message(MSG_INFO, Str.str(), 0, 0) );
			Str.str("");
			//return iCapTuneRes;
			return 1;
		};
		Notify( LMS_Message(MSG_INFO, "VCO is not suitable.\n", 0, 0) );
	};
	string str = "Tune: VCO can not deliver required frequency.\n\
Communication problems?\n\
Please check SPI cable, connection etc.\n\n\
VCO and CAP changed back to initial values\n";
	Notify( LMS_Message(MSG_ERROR, str, 0, 0) );

	// Set CAP and VCO to initial values
	SetParam(Rx ? VCOCAP_RXPLL : VCOCAP_TXPLL, iInitCap);
	SetParam(Rx ? SELVCO_RXPLL : SELVCO_TXPLL, indexToSELVCO_FRANGE(iInitVco));
	return 0;
}

/** @brief Sets CLK_EN by mask
    @param mask enabled clocks bits
*/
void LMS6002_MainControl::EnableSPIClocksByMask(const unsigned int mask)
{
    unsigned value = GetParam(CLK_EN, true, true);
    m_SPIclocksBackup = value;
    value |= mask;
    SetParam(CLK_EN, value);
}

void LMS6002_MainControl::RestoreAllSPIClocks()
{
    SetParam(CLK_EN, m_SPIclocksBackup);
}
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

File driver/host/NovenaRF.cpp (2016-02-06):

////////////////////////////////////////////////////////////////////////
// SoapySDR module for Novena-RF SDR
//
// Copyright (c) 2015-2015 Lime Microsystems
// Copyright (c) 2015-2015 Andrew "bunnie" Huang
// SPDX-License-Identifier: Apache-2.0
// http://www.apache.org/licenses/LICENSE-2.0
////////////////////////////////////////////////////////////////////////

#include "NovenaRF.hpp"
#include "xilinx_user_gpio.h"
#include "novena_rf.h" //shared kernel module header
#include <SoapySDR/Registry.hpp>

#include <sys/ioctl.h>
#include <sys/types.h>
#include <sys/stat.h>
#include <fcntl.h>
#include <sys/mman.h> //mmap
#include <unistd.h> //close

/***********************************************************************
 * Device interface
 **********************************************************************/
NovenaRF::NovenaRF(const std::string &fpgaImage):
    _novena_fd(-1),
    _irq_fd(-1),
    _regs(nullptr),
    _framer0_mem(nullptr),
    _deframer0_mem(nullptr),
    _lms6ctrl(nullptr)
{
    setvbuf(stdout, NULL, _IOLBF, 0);

    //open the file descriptor for the novena rf module
    _novena_fd = open(NOVENA_RF_DEVFS, O_RDWR | O_SYNC);
    if (_novena_fd <= 0)
    {
        throw std::runtime_error("Failed to open " NOVENA_RF_DEVFS ": " + std::string(strerror(errno)));
    }

    //open the sysfs gpio used for IRQ
    gpio_export(FPGA_IRQ_GPIO);
    _irq_fd = gpio_fd_open(FPGA_IRQ_GPIO);
    if (_irq_fd <= 0)
    {
        throw std::runtime_error("Failed to open FPGA_IRQ_GPIO: " + std::string(strerror(errno)));
    }
    gpio_set_edge(FPGA_IRQ_GPIO, "rising");

    //initialize the EIM configuration
    int ret = ioctl(_novena_fd, NOVENA_RF_EIM_INIT);
    if (ret != 0)
    {
        throw std::runtime_error("Failed to initialize EIM " + std::string(strerror(errno)));
    }

    //map the register space
    _regs = mmap(NULL, NOVENA_RF_REGS_PAGE_SIZE, PROT_READ | PROT_WRITE, MAP_SHARED, _novena_fd, NOVENA_RF_MAP_OFFSET(NOVENA_RF_REGS_PAGE_NO));
    if (_regs == MAP_FAILED)
    {
        throw std::runtime_error("Failed to map regs " + std::string(strerror(errno)));
    }

    //load the fpga image and verify version
    this->fpgaCheckAndLoad(fpgaImage);

    //self test on register space and bus
    this->selfTestBus();

    //clear hardware time
    this->setHardwareTime(0, "");

    //map the RXD and TXD memory space
    _framer0_mem = mmap(NULL, NOVENA_RF_FRAMER0_PAGE_SIZE, PROT_READ | PROT_WRITE, MAP_SHARED, _novena_fd, NOVENA_RF_MAP_OFFSET(NOVENA_RF_FRAMER0_PAGE_NO));
    if (_framer0_mem == MAP_FAILED)
    {
        throw std::runtime_error("Failed to map framer memory " + std::string(strerror(errno)));
    }
    _deframer0_mem = mmap(NULL, NOVENA_RF_DEFRAMER0_PAGE_SIZE, PROT_READ | PROT_WRITE, MAP_SHARED, _novena_fd, NOVENA_RF_MAP_OFFSET(NOVENA_RF_DEFRAMER0_PAGE_NO));
    if (_deframer0_mem == MAP_FAILED)
    {
        throw std::runtime_error("Failed to map deframer memory " + std::string(strerror(errno)));
    }

    //initiate communication with the frontend
    this->initRFIC();

    //defaults for internal testing
    this->writeRegister(REG_LMS_TRX_LOOPBACK, 0); //disable loopback
    this->writeRegister(REG_TX_IDLE_LEVEL_LO, 0); //DUC input idles 0
    this->writeRegister(REG_TX_IDLE_LEVEL_HI, 0); //DUC input idles 0

    //initialize the DMA channels
    this->initDMAChannels();

    //default to offset removal on
    this->setDCOffsetMode(SOAPY_SDR_RX, 0, true);

    //reset cordics
    this->setFrequency(SOAPY_SDR_RX, 0, "BB", 0.0, SoapySDR::Kwargs());
    this->setFrequency(SOAPY_SDR_TX, 0, "BB", 0.0, SoapySDR::Kwargs());

    //provide a value for the rate until set
    _cachedSampleRates[SOAPY_SDR_RX] = 0.0;
    _cachedSampleRates[SOAPY_SDR_TX] = 0.0;
}

NovenaRF::~NovenaRF(void)
{
    this->exitRFIC();
    munmap(_regs, NOVENA_RF_REGS_PAGE_SIZE);
    munmap(_framer0_mem, NOVENA_RF_FRAMER0_PAGE_SIZE);
    munmap(_deframer0_mem, NOVENA_RF_DEFRAMER0_PAGE_SIZE);
    close(_novena_fd);
    gpio_fd_close(_irq_fd);
}

/*******************************************************************
 * FPGA checks and loading
 ******************************************************************/
void NovenaRF::fpgaCheckAndLoad(const std::string &fpgaImage)
{
    //hash the fpga image
    uint16_t imageHash = uint16_t(novenaRF_hashFpga(fpgaImage));

    //first access turns the bus clock on -- if it was not on...
    this->readRegister(REG_SENTINEL_ADDR);

    //check if the fpga image was loaded -- if not load it
    if (
        this->readRegister(REG_SENTINEL_ADDR) != REG_SENTINEL_VALUE or
        this->readRegister(REG_VERSION_ADDR) != REG_VERSION_VALUE or
        this->readRegister(REG_LOOPBACK_ADDR) != imageHash)
    {
        novenaRF_loadFpga(fpgaImage);
    }

    //check the fpga image and its version number
    const int fpgaSentinel = this->readRegister(REG_SENTINEL_ADDR);
    if (fpgaSentinel != REG_SENTINEL_VALUE)
    {
        SoapySDR::logf(SOAPY_SDR_ERROR, "Expected FPGA sentinel 0x%x, but got 0x%x", REG_SENTINEL_VALUE, fpgaSentinel);
        throw std::runtime_error("Fail FPGA sentinel check");
    }

    const int fpgaVersion = this->readRegister(REG_VERSION_ADDR);
    if (fpgaVersion != REG_VERSION_VALUE)
    {
        SoapySDR::logf(SOAPY_SDR_ERROR, "Expected FPGA version 0x%x, but got 0x%x", REG_VERSION_VALUE, fpgaVersion);
        throw std::runtime_error("FPGA version mismatch");
    }

    //perform reset on FPGA internals
    this->writeRegister(REG_RESET_ADDR, 1);
    this->writeRegister(REG_RESET_ADDR, 0);

    //store the hash in the loopback
    this->writeRegister(REG_LOOPBACK_ADDR, imageHash);
}
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

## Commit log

2014-05-15 Revision number added to silk, and MyriadRF to PDFs
    [Analog Circuits.sch, Clocks, RF FE.sch, Connectors.sch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]
2014-10-09 Fixed shorts
    [Analog Circuits.sch, Clocks, RF FE.sch, Connectors.sch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]
2014-11-16 Added FPGA project
    [top.sch]
2015-01-18 began work on driver stubs
2015-01-18 added stream fifo for implementation of framer/deframer
2015-01-19 save partial progress on the framer
2015-01-19 fill in the status reporting, time mux, and frame end signal
2015-01-20 fixes for framer after begining simulation
2015-01-21 use library work on framer modules
2015-02-07 novena: device time set/get
2015-02-08 novena: work on dma mm2s and s2mm blocks
2015-02-08 novena: work on dma ctrl fifos, and fpga hash check
2015-02-08 novena: dma loopback test + s2mm fixes
    [NovenaRF.cpp]
2015-02-08 novena: install framer and deframer
2015-02-08 novena: hooking in the spi mod for lms gpios
2015-02-08 novena: work on DMA SG table management
2015-02-09 novena: cleanup dma channel implementation
2015-02-09 novena: framer header functions + dma test
2015-02-09 novena: deframer header functions + dma test
2015-02-09 novena: implement ignores for dma wait
2015-02-11 novena: first attempt HB filter chains
2015-02-11 Update README.md
    Add note about driver not being ready.
2015-02-12 novena: many tweaks, loopback through filter chain OK
2015-02-12 novena: 1-bit truncation for filter loss adjustment
2015-02-13 Squashed 'lms-suite/' content from commit 7fbf765
    git-subtree-dir: lms-suite
    git-subtree-split: 7fbf765d3ff6c95c98e5aa7a1659766ded7e27f6
    [About.obj, clUARFCN.obj, common.obj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]
2015-02-13 novena: filled in enabled and gain hooks, switches
2015-02-14 novena: move band switches into antenna api
2015-02-15 novena: fsync polarity and calibrate
2015-02-16 novena: irq for dma status w/ masks
2015-02-16 novena: additional documentation for driver
2015-02-16 novena: additional docs for detecting the device
2015-02-16 novena: additional device properties in the readme
2015-02-17 novena: only end burst if the last sample can be released
2015-02-25 novena: fix sample rate checker
    [NovenaRF.cpp]
2015-02-25 novena: dma gpio poll fix for spurious wakes
2015-02-25 novena: fix dma wait loop, needs to break to clear mask
    [NovenaRF.cpp]
2015-02-27 novena: added dc offset removal in ddc chain
2015-03-08 novena: fix missing stdlib include
    [twbw_helper.h]
2015-04-09 novena: gpio poll is having wakeup issues, switching to usleep
2015-05-09 novena: fix fpga load with spidev buffer size
    The max buffer size is 32 bytes
    [LoadFPGA.cpp, NovenaRegs.hpp]
2015-05-12 novena: implement call to query DMA buffer addrs
2015-11-22 Supplement kernel module building instructions.
    This change adds more wording to the instructions for building the
    kernel module. It also includes a prebuilt module for the current kernel
    version (3.19-novena-r39).
2016-02-06 novena: provide a value for the rate until set, fixes #21
    [NovenaRF.cpp]
